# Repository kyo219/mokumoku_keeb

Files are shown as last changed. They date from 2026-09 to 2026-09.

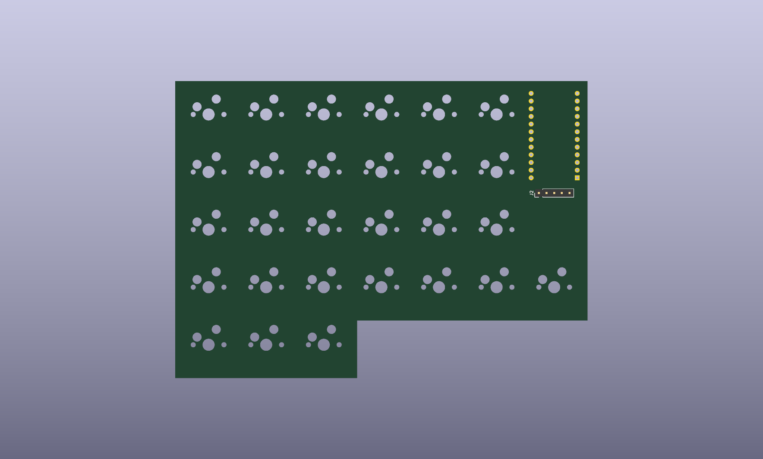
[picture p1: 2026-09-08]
assets/renders/pcb-left-top.png

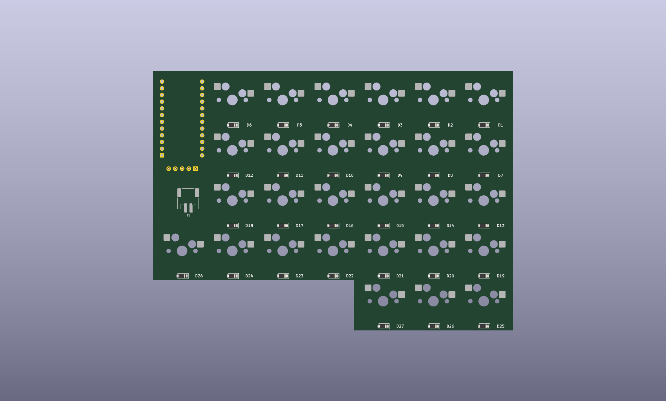
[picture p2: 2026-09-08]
assets/renders/pcb-left-bottom.png

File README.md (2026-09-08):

# mokumoku-keeb(仮称)

左右分割型・ワイヤレス・オーソリニアキーボードの設計リポジトリです。

> **注意**: `mokumoku-keeb` はリポジトリ名由来の仮slugです。正式な製品名は未定です。

## 現在の開発段階

**初期整備フェーズ(設計段階)** — 要件定義とドキュメント整備を行っている段階です。
KiCadの回路図・PCB、ケースCAD、製造データはまだ存在しません。**製造検証前であり、発注可能な状態ではありません。**

## 主な仕様

- 左右分割型オーソリニア配列(列スタッガー・キー回転なし)
- **片側28キー / 左右合計56キー**、全キー1u、キーピッチ19.05mm
- Cherry MX互換スイッチ(通常高さ、3ピン/5ピン対応)+ **Kailh MXホットスワップソケット**
- マイコン: **nice!nano v2**(または互換のPro Micro形状nRF52840)を左右に各1基、ソケット実装
- ディスプレイ: **nice!view**(左右各1、ソケット実装、nice!nanoの上に積層)
- ファームウェア: **ZMK**
- 接続: **Bluetooth LE**(ホスト接続・左右間ともに無線。TRRSケーブル不使用)
- 電源: 左右独立の3.7V LiPoバッテリー + 2ピンJSTコネクタ、USB-C充電
- **LED非搭載**(キーLED・RGB・アンダーグローなし)— 省電力・薄型化を優先
- MX互換を維持したまま可能な限り薄い、薄型サンドイッチ構造を基本案とする

## ドキュメント

| ドキュメント | 内容 |
| --- | --- |
| [docs/product-requirements.md](docs/product-requirements.md) | **仕様の一次情報**。確定要件・未確定事項の整理 |
| [docs/key-layout.md](docs/key-layout.md) | キー配列の定義(論理座標・ミラー規則) |
| [docs/architecture.md](docs/architecture.md) | システム構成図 |
| [docs/electrical.md](docs/electrical.md) | 電気設計(確定事項と検討中の候補) |
| [docs/mechanical.md](docs/mechanical.md) | 機構設計(プレート・ケース・積層) |
| [docs/firmware.md](docs/firmware.md) | ZMKファームウェア方針 |
| [docs/manufacturing.md](docs/manufacturing.md) | 製造方針(Rev.A) |
| [docs/bring-up.md](docs/bring-up.md) | 初号機のbring-up手順 |
| [docs/verification-checklist.md](docs/verification-checklist.md) | 3段階の検証チェックリスト |
| [docs/references.md](docs/references.md) | 参考資料・公式資料・ライセンス記録 |
| [docs/decisions/](docs/decisions/) | 設計判断のADR |
| [docs/revisions/rev-a.md](docs/revisions/rev-a.md) | Rev.Aの記録 |

## リポジトリ構成

```
.
├── AGENTS.md                 # AI・開発者向けの編集ルール
├── README.md
├── docs/                     # 仕様・設計ドキュメント(上表参照)
├── hardware/kicad/           # KiCadソース(回路図・PCB・プロジェクト固有ライブラリ)
├── mechanical/               # ケース・プレートのCADと出力物
├── firmware/zmk/             # ZMK設定・Shield定義
├── production/               # 発注用に凍結した製造データ(リビジョン別)
├── scripts/                  # 補助スクリプト
└── assets/renders/           # レンダリング画像等
```

このリポジトリを編集する際は、まず [AGENTS.md](AGENTS.md) を読んでください。

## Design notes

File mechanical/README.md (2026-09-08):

# mechanical/

ケース・プレートの機構設計を置くディレクトリ。設計方針は `docs/mechanical.md` を参照。
**CADデータはまだ作成していない**(初期整備フェーズ)。

| サブディレクトリ | 用途 |
| --- | --- |
| `cad/` | 編集可能なCADソース(FreeCAD / Fusion等。形式は未確定) |
| `plates/` | スイッチプレート(約1.5mm厚候補)の設計データ |
| `case/` | ケース(トップ・ボトム)の設計データ |
| `exports/` | STL / STEP / DXF などの出力物 |

- ソース(`cad/`)と出力物(`exports/`)を分離する。
- 発注に使う製造データは `production/<revision>/` へ凍結する(AGENTS.md参照)。

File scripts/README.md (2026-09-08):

# scripts/

補助スクリプト。標準ライブラリのみ使用(現状は追加依存なし。必要になったらuvで環境構築)。

| スクリプト | 役割 |
| --- | --- |
| `generate_left_schematic.py` | ADR-0002のマトリクス/GPIO定義から左基板回路図(`hardware/kicad/left/`)を生成。**回路図は生成物、こちらが編集対象**。ピン変更時はADR/electrical.mdと同時更新して再生成する |
| `verify_left_netlist.py` | 生成した回路図のネットリストをkicad-cliで書き出し、ADR-0002の期待結線(全COL/ROW/nice!view/電源ネット)と自動照合する |
| `generate_footprints.py` | カスタムフットプリント(`hardware/kicad/footprints/mokumoku_keeb.pretty/`)を公式データシート由来の座標で生成。検証状態は footprints/README.md の表を参照 |
| `generate_left_pcb.py` | 左基板PCBを生成(KiCad付属python3で実行)。ネットリスト読込→28キー配置→裏面ダイオード→nano/view/JST配置→切り欠き外形→アンテナkeep-out。配線は含まない |
| `render_concept_layout.py` / `render_side_view.py` | 概観モック(上面・断面)を `assets/renders/` に生成 |

前提: KiCad 10が `~/Applications/KiCad/` にあること。

```
python3 scripts/generate_left_schematic.py
python3 scripts/verify_left_netlist.py
~/Applications/KiCad/KiCad.app/Contents/MacOS/kicad-cli sch erc --severity-all \
  hardware/kicad/left/mokumoku_keeb_left.kicad_sch
```

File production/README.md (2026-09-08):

# production/

発注に使用した**製造データの凍結スナップショット**をリビジョン別に置くディレクトリ。**まだ製造データは存在しない**(発注可能な状態ではない)。

## 構成(予定)

```
production/
└── rev-a/
    ├── gerbers/     # Gerber・ドリル
    ├── bom/         # BOM
    ├── placement/   # 座標データ(CPL)
    └── README.md    # 発注日・発注先・仕様・元コミットの記録
```

## ルール

- ここへ置けるのは、`docs/verification-checklist.md` の製造前チェックリストを完了したデータのみ。
- 置いたデータは**凍結**し、以後編集しない。修正は次リビジョン(`rev-b/` 等)として作成する。
- 製造用の生成物をこのディレクトリ以外に置かない(AGENTS.md参照)。

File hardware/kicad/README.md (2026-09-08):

# hardware/kicad/

KiCadの**編集可能なソース**を置くディレクトリ。KiCad 10.0系を使用(`~/Applications/KiCad`)。

## 構成

- `left/` — **左基板プロジェクト(正)**。回路図はRev.Aドラフトあり(`scripts/generate_left_schematic.py` で生成、ERC 0違反・ネットリスト自動照合済み)。PCBは未着手
- `symbols/` — プロジェクト固有シンボル(`mokumoku_keeb.kicad_sym`: nice_nano_v2 = 公式ピン配置図と照合済み)
- `footprints/` — プロジェクト固有フットプリント(`.pretty`、まだなし)
- `3dmodels/` — 3Dモデル(まだなし)
- 右基板は左のミラーとして後続フェーズで生成(ADR-0001)

## 置かないもの

- Gerber・ドリル・BOM・座標データなどの**生成物** → `production/<revision>/` へ(AGENTS.md参照)

## ルール

- フットプリントは実部品データシートと照合し、検証状態を記録してから製造に使用する(未検証フットプリントの製造使用は禁止)。
- 外部ライブラリ由来のシンボル・フットプリントは出典とライセンスを `docs/references.md` に記録する。
- ERC/DRCを通してから製造候補とする。

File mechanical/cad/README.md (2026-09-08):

# cad/

編集可能なCADソースを置く(まだなし)。使用CADツール・ファイル形式は未確定。

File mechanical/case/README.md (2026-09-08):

# case/

ケースの設計データを置く(まだなし)。材質・固定方法は未確定(`docs/mechanical.md` 参照)。USB-C・リセット・電源スライドスイッチの開口とアンテナ周辺の非金属化が要件。

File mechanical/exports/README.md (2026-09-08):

# exports/

CADからの出力物(STL / STEP / DXF等)を置く(まだなし)。編集可能なソースは `cad/` へ。発注用データは `production/<revision>/` へ凍結する。

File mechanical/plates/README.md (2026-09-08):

# plates/

スイッチプレートの設計データを置く(まだなし)。約1.5mm厚を検討中。MX互換の開口寸法は公式資料照合後に確定する(`docs/mechanical.md` 参照)。

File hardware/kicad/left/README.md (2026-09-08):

# hardware/kicad/left/ — 左基板KiCadプロジェクト

左半分(正)のKiCadプロジェクト。**回路図・PCBともスクリプトによる生成物**であり、結線・配置の手編集は禁止(変更はADR・docs・スクリプトを同時更新して再生成)。

- `mokumoku_keeb_left.kicad_sch` — 回路図(`scripts/generate_left_schematic.py` の生成物、フットプリント割り当て済み)
- `mokumoku_keeb_left.kicad_pcb` — PCB(`scripts/generate_left_pcb.py` の生成物。**配置+外形+アンテナkeep-outまで。配線は未着手**)
- `mokumoku_keeb_left.kicad_pro` / `sym-lib-table` / `fp-lib-table` — プロジェクト設定とライブラリ参照

## 検証

```
python3 scripts/generate_left_schematic.py   # 回路図再生成
python3 scripts/verify_left_netlist.py       # ネットリストをADR-0002と自動照合
kicad-cli sch erc ...left.kicad_sch          # ERC(現在0違反)
<KiCad付属python3> scripts/generate_left_pcb.py   # PCB再生成
kicad-cli pcb drc ...left.kicad_pcb          # DRC(現在: 未配線92件のみ、他0違反)
```

## 状態・注意

- **Rev.Aドラフト。配線未着手であり製造可能ではない。**
- PCBの内容: 28キー(19.05mmグリッド、R0C0=(50,50))、裏面ダイオード、nice!nano(アンテナ=上端向き、ADR-0007)、nice!view用5ピンヘッダ、JST(裏面・C6タブ下部)、切り欠き外形、アンテナkeep-out rule area
- **SW29(スライドスイッチ)・SW30(リセット)は未配置**(検証済みフットプリントがないため。Alps図面入手・リセット部品選定後に配置)
- JST極性は「pin1=+」の**仮置き**(回路図上に注記あり)。実バッテリー確認後に確定(ADR-0003)。
- 右基板は本プロジェクトのミラーとして後続フェーズで生成する(ADR-0001)。

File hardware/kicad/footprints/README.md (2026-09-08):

# footprints/ — フットプリントと検証状態

**未検証のフットプリントを製造用に使用しない**(AGENTS.md)。使用するフットプリントは必ずこの表で状態を管理する。

カスタム品は `mokumoku_keeb.pretty/`(`scripts/generate_footprints.py` の生成物。手編集禁止、変更はスクリプト側で)。

| 部品 | フットプリント | 出所 | 検証状態 |
| --- | --- | --- | --- |
| MXスイッチ+Kailhホットスワップ | `mokumoku_keeb.pretty/SW_MX_HotSwap_Kailh_PG151101S11_1u` | 自作(Cherry MX公式+Kailh公式データシートから生成) | **図面照合済み**(穴位置=Cherry公式、Ø3.0ソケット穴=Kailh公式、pcbnewで座標を数値検証)。⚠️ SMDパッドの張り出し量(±3.175mm)は図面からの導出値 → **実物ソケットで発注前に要確認** |
| nice!nano v2(ソケット) | `mokumoku_keeb.pretty/nice_nano_v2` | 自作(2.54mmピッチ、行間15.24mm=Pro Micro慣例) | **暫定**。ピン番号=プロジェクトシンボルと一致(数値検証済み)。⚠️ ドリル1.0mmは**コンスルー公式図面で要確認**(ADR-0006)。外形・アンテナ領域は近似値 → 実物採寸で確定 |
| バッテリーコネクタ | `Connector_JST:JST_PH_S2B-PH-SM4-TB_1x02-1MP_P2.00mm_Horizontal`(KiCad標準) | KiCad公式ライブラリ(ePH.pdf準拠と明記) | **図面照合済み**(ピッチ2.0±0.05・補強パッド1.5×3.4が公式図面と一致)。⚠️ **極性(pin1=+の仮置き)は実バッテリーで要確認**(ADR-0003) |
| ダイオード 1N4148W | `Diode_SMD:D_SOD-123`(KiCad標準) | KiCad公式ライブラリ | **採用可**(SOD-123標準パッケージ。メーカー推奨パッドとの差異は手はんだ用途で許容) |
| nice!view 5ピン | `Connector_PinHeader_2.54mm:PinHeader_1x05_P2.54mm_Vertical`(KiCad標準) | KiCad公式ライブラリ | **採用可**(標準2.54mmピッチ)。ソケット高さ選定はADR-0006 |
| 電源スライドスイッチ SSSS811101 | **未作成** | — | **Alps公式PDF図面が未入手のため作らない**(推測で作成しない方針)。図面入手後に作成・照合 |
| リセットボタン | **未作成** | — | 型番未定のため未作成 |

## 検証ワークフロー

```
python3 scripts/generate_footprints.py     # カスタムFP再生成
# pcbnewで検証ボードに配置 → 座標数値チェック+PDF目視(scripts/内の手順参照)
```

発注前チェックリスト(docs/verification-checklist.md)で、上表の⚠️項目がすべて解消していることを確認すること。

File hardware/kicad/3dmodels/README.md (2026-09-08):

# 3dmodels/

KiCadで使用する部品の3Dモデルを置く(まだなし)。外部由来のモデルは出典・ライセンスを `docs/references.md` に記録すること。

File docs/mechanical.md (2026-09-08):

# 機構設計(Mechanical)

薄型化を重視するが、**通常高さのMX互換性と機械的強度を優先**する。

## 確定している機構要件

- 基本キーピッチ **19.05mm**、全キー1u、列スタッガー・回転なし
- 通常高さの**MX互換スイッチ**(3ピン/5ピン対応)+ Kailh MXホットスワップソケット
- **プレートなし構成にはしない**。**1.5mm厚のスイッチプレート**を用いた**薄型サンドイッチ構造**を基本案とする
  - Cherry公式データシート確認済み: **プレート開口14.0±0.05mm角(角R0.3max)、プレート厚1.5±0.1mm指定**([references.md](references.md))。1.5mm案は公式仕様どおり
  - 同データシートのPCB厚表記は約1.5mm(0.06±0.006in)→ **1.2mm板厚はCherryの想定外**であり、検証必須の追加根拠
- PCB厚は1.6mmを標準候補(1.2mmはソケット互換性・剛性確認後に判断)
- ホットスワップソケットと底板のクリアランスを最小化する
- キーLED等がないため、導光・透過に関する機構要件はない

## 基板・プレート外形の方針(確定)

- **PCB・プレート・ケースの外形は長方形にせず、キー領域に沿って切り欠く**([key-layout.md](key-layout.md) の外形方針に従う)。
- 具体的には、下段追加行(R4)は小指側3キー分のみ張り出し、その右側の下部領域(R4×C3–C6相当)は基板なし。親指側C6タブは1uキー+nice!view/nice!nano占有分のみ。
- ケース・プレートも同じ輪郭に追従させる(ケース余白・入隅Rは外形設計時に確定)。
- 注意点: 切り欠き形状のため、ねじ・スペーサー配置と剛性(特にC6タブと下段張り出しの根元)を外形設計時に確認する。

## 積層構造(基本案)

上から順に:

```
キーキャップ
MX互換スイッチ
スイッチプレート(約1.5mm)
(プレート〜PCB間の空間: MX規格による)
PCB(1.6mm標準候補)
ホットスワップソケット・ダイオード(PCB裏面)
(最小クリアランス)
底板
```

- **ホットスワップソケット(Kailh PG151101S11)のPCB裏面からの突出は1.85±0.1mm**(公式データシート確認済み)。PCB裏面〜底板の最小クリアランスはこの1.85mm+マージンが下限になる。
- Kailh公式の推奨レイアウトは**基板厚1.6mm前提**と明記されている。PCB1.2mm化はスイッチ保持力・ソケット嵌合の実物検証をしてから判断する(既存方針の根拠)。

- MXスイッチはプレート上面からPCB上面までの距離が規格で決まるため(データシートで確認)、薄型化の自由度は主に「PCB裏面〜底板」と「ケース縁の高さ」にある。
- スイッチのセンターポスト・固定ピンがPCBを貫通するため、底板との間に必要な逃げを確認する。

## nice!view / nice!nano の積層

- 追加1uキー(R3, C6)の真上の領域に **nice!view(公式確認済み: 14mm × 36mm、5ピン2.54mmピッチ)を縦向きに配置**し、その**下層にnice!nano(公式確認済み: 基板厚3.2mm、ミッドマウントUSB-C)を積層**する。
- 両方とも交換可能なソケット実装。ソケット+ピンヘッダの合計高さが確定するまで、この部分の最大高さは未確定。
- **nice!view装着中でも以下を操作可能にする**こと:
  - USB-C(ケース開口から抜き差し)
  - リセットボタン
  - 電源スライドスイッチ
- ソケットの具体部品(低背ソケット/コンスルー等)は未確定(ADR予定)。

## バッテリー配置

- 左右それぞれにLiPoを収納する。配置場所は未確定(候補: PCB下の空間のうちホットスワップソケット・アンテナ禁止領域と干渉しない領域)。
- **保護要件**:
  - ソケット・はんだ接合部の突起がバッテリーに接触しない構造にする
  - 底板との間で圧迫しない
  - **膨張余裕**(厚み方向のマージン)を確保する
- バッテリー寸法・容量は未確定。ケース内寸確定後に決める([product-requirements.md](product-requirements.md) 未確定事項)。

## ケース開口・操作部

| 操作部 | 要件 |
| --- | --- |
| USB-C | ケース装着後も抜き差し可能な開口 |
| リセットボタン | ケース外から操作可能(開口またはピンホール) |
| 電源スライドスイッチ | ノブをケース**側面**から操作可能。ON/OFF位置を目視・触覚で判別可能。ケースまたはPCBにON/OFF表示。ノブの突出量を抑えて誤操作を防ぐ。**配置方針(2026-09-08、暫定): C6タブの外周側面、nice!view下部〜親指キー横**(アンテナkeep-outから離れ、nice!view/nano・JSTと近く配線が短い)。右半分はミラー |

## アンテナ周辺

- nice!nanoのアンテナ端周辺は**非金属化**する: 金属プレート・ねじ・バッテリー・金具を配置しない。
- プレートを金属にする場合でも、アンテナ上方は切り欠くか非金属材にする(材質未確定のため後続フェーズで具体化)。

## ケース製作方針(2026-09-08確定、ADR-0008)

- **フル樹脂の削り出しを基本方針**とする(POM/PC候補、具体材質未定)。フルアルミはアンテナ遮蔽のため不採用。
- 進め方: PCBレイアウト確定 → **3Dプリント試作**(干渉・開口・BLE実測検証)→ 樹脂削り出し発注。
- CADはCadQuery等でのスクリプト生成を基本とし、PCB外形に追従させる。発注データは `production/<revision>/` に凍結。

## 未確定事項

- ケースの具体材質(POM / PC等)・色と固定方法(ねじ/スペーサー構成)
- プレート材質(FR4 / ポリカーボネート / アルミ(アンテナ部除く)等)
- 正確な外形寸法・ケース余白(nice!view 14×36mmは確認済み。ソケット高さと余白が未確定)
- nice!view/nice!nanoソケットの型番と積層高さ
- バッテリー寸法・配置
- 底板とソケット間の具体的クリアランス値

これらは実部品の公式寸法資料([references.md](references.md))を確認後、ADRで確定する。

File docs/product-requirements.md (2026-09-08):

# 製品要件定義(Product Requirements)

**このドキュメントが仕様の一次情報です。** 他のドキュメントと矛盾した場合はこちらが正です。

- プロジェクト名: **mokumoku-keeb(仮称)** — リポジトリ名由来の仮slug。正式名は未定。
- ステータス: 初期整備フェーズ(設計段階、製造検証前)

## 1. 確定要件

### 製品コンセプト

- 左右分割型・Bluetooth対応・バッテリー駆動のオーソリニアキーボード
- 通常高さのMX互換スイッチを使用しつつ、LEDを省略し、省電力かつ可能な限り薄い構造を目指す
- 薄型化より、MX互換性と機械的強度を優先する

### キー配列(詳細は [key-layout.md](key-layout.md))

- 左半分を基準に設計し、右半分は完全な左右反転形状
- 基本4行×6列のオーソリニア24キー + 小指側3列の第5行3キー + 親指側1uキー1個 = **片側28キー、左右合計56キー**
- 全キー1u、基本キーピッチ19.05mm
- 列スタッガー・キー回転は使用しない
- 追加の1uキーはSpace専用ではなく汎用キーとして扱う
- **基板・プレート・ケースの外形は長方形にせず、キー領域(+nice!view/nice!nano領域)に沿って切り欠く**。キーが入らない領域(R4×C3–C6相当の下部など)には基板を設けない(2026-09-08確定。詳細は [key-layout.md](key-layout.md))

### スイッチ

- 通常高さのCherry MX互換スイッチ(3ピンおよび5ピン対応)
- Kailh MXホットスワップソケット
- Kailh Choc等のロープロファイル規格には**対応しない**
- 全キーにマトリクス用ダイオードを設ける
- キーLED・RGB LED・アンダーグローは**搭載しない**

### マイコン・無線

- 左右それぞれに独立したnRF52840マイコン
- nice!nano v2、または互換性が明確なPro Micro形状のnRF52840マイコン
- Raspberry Pi Pico / RP2040 は**使用しない**
- マイコンは交換可能な低背ソケット実装
- ファームウェアはZMK
- ホスト接続・左右間接続ともにBluetooth LE(TRRS等の有線接続は使用しない)
- ケース装着後もUSB-Cを利用可能にする
- Bluetoothアンテナの禁止領域(keep-out)を確保する

### nice!view

- ディスプレイはnice!view専用(OLED互換性は不要)
- 標準的な5ピン接続とSPI配線に対応
- 左半分では親指側追加1uキー(R3, C6)の真上へ縦向きに配置、右半分は左右反転
- nice!viewの下に重なるようにnice!nanoを配置
- nice!view・nice!nanoともに交換可能なソケット実装
- 電源スイッチ・リセット・USB-Cはnice!view装着中も操作可能にする
- nice!viewはキー数に含めない

### バッテリー・電源

- 左右それぞれ独立した3.7V LiPoバッテリーで駆動
- 左右それぞれに2ピンJSTバッテリーコネクタを搭載
- nice!nanoのUSB-C経由で充電
- 左右それぞれにリセットボタンを設置
- 電源はON/OFF位置が明確な2ポジション式スライドスイッチ
  - スライドノブはケース側面から操作可能
  - ON/OFF状態を目視および触覚で判別可能にする
  - PCBまたはケースにON/OFF表示を設ける
  - 持ち運び中の誤操作を防ぐため、ノブの突出量を抑える
- LiPoをソケット・はんだ接合部・底板から保護し、膨張余裕を確保する

### 開発プロセス

- 初号機(Rev.A)はPCBのみを発注し、手実装する
- Rev.Aを評価し、必要に応じてRev.Bで修正する
- 未確認の寸法・ピン配置・極性・フットプリントを推測で確定しない
- 「製造可能」「検証済み」「production-ready」等の表現は条件を満たすまで使用しない

## 2. 推奨要件(基本案。検証結果により変更可)

- プレートなし構成にはせず、**薄型サンドイッチ構造**を基本案とする
- スイッチプレートは約**1.5mm厚**を検討する
- PCB厚は**1.6mmを標準候補**とし、1.2mmは互換性(ホットスワップソケット・スイッチ保持力)と剛性を確認してから判断する
- ホットスワップソケットと底板のクリアランスを最小化する
- アンテナ周辺へ銅箔・金属プレート・バッテリー・ねじを配置しない

## 3. 未確定事項

| # | 項目 | 決定方法 | 記録先 |
| --- | --- | --- | --- |
| 1 | 正式な製品名 | ユーザーが決定 | 本ドキュメント |
| 2 | ~~左右別PCB か リバーシブルPCB か~~ | **確定: 左右別PCB**([decisions/0001](decisions/0001-separate-left-right-pcbs.md)) | 確定済み |
| 3 | PCB厚(1.6mm標準候補 / 1.2mm) | ソケット互換性・剛性の確認後 | [decisions/](decisions/) |
| 4 | ~~マトリクス構成~~ | **確定: 物理一致の5行×7列**([decisions/0002](decisions/0002-matrix-and-gpio.md)) | 確定済み |
| 5 | ~~GPIO割り当て~~ | **確定**([decisions/0002](decisions/0002-matrix-and-gpio.md)。PCB配線でRow/Col個別入れ替えの可能性のみ残る) | 確定済み |
| 6 | バッテリーの寸法と容量 | **500mAh以下方針は確定**([decisions/0004](decisions/0004-power-slide-switch-alps.md))。具体型番はケース内寸確定後 | ADR |
| 7 | JSTコネクタ | **型番確定: JST PH / S2B-PH-SM4-TB**([decisions/0003](decisions/0003-battery-connector-jst-ph.md))。**極性のみ実バッテリー確認後** | 極性のみ未確定 |
| 8 | ~~スライドスイッチの型番~~ | **確定: Alps SSSS811101**([decisions/0004](decisions/0004-power-slide-switch-alps.md)。BOOST充電は使用禁止) | 確定済み |
| 9 | プレート・ケースの材質と固定方法 | **ケースはフル樹脂削り出し方針で確定**([decisions/0008](decisions/0008-case-material-resin.md)、POM/PC候補)。具体材質・固定方法・プレート材質は未確定 | [mechanical.md](mechanical.md) / ADR |
| 10 | nice!view / nice!nano ソケット | **方式確定: コンスルー第一候補**([decisions/0006](decisions/0006-mcu-display-sockets.md))。型番・高さは図面確認後 | 型番のみ未確定 |
| 11 | ~~ダイオードの型番・実装形態~~ | **確定: 1N4148W(SOD-123)**([decisions/0005](decisions/0005-matrix-diode-1n4148w.md)) | 確定済み |
| 12 | 正確な外形寸法(ケース余白に依存。nice!view寸法は14×36mmで確認済み) | 後続フェーズ | [mechanical.md](mechanical.md) |

## 4. 対象外(スコープ外)

- キーLED・RGB LED・アンダーグロー
- Kailh Choc等のロープロファイルスイッチ対応
- OLEDディスプレイ互換
- TRRS等の有線での左右接続
- Raspberry Pi Pico / RP2040系マイコン
- 列スタッガー・キー回転を伴う配列
- (初期フェーズでは)KiCad回路図・PCB・Gerber・製造データ・ケースCADの完成、製造発注、外部サービスへのアップロード

## 5. 初号機(Rev.A)の成功条件

Rev.A(PCBのみ発注・手実装)が以下をすべて満たすこと:

1. 短絡・逆極性なくUSB-Cから給電・充電できる
2. nice!nanoがソケット実装で認識され、ZMKを書き込める
3. 全56キーがマトリクスとして正しく入力される(ゴースト・チャタリングの構造的問題がない)
4. nice!viewがソケット実装で表示動作する
5. 左右間がBLEで接続され、ホストともBLE接続できる
6. 左右それぞれがバッテリー単独で駆動する
7. アンテナ禁止領域が確保され、実用的なBLE接続性が得られる
8. ケース装着を想定した部品高さ・開口位置に致命的な干渉がない(ケース自体はRev.A時点で完成していなくてよい)

満たせなかった項目はRev.Bの修正対象として [revisions/rev-a.md](revisions/rev-a.md) に記録する。

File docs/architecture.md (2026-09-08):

# システム構成(Architecture)

左右分割・完全無線のシステム構成を示す。左右は対称構成(右は物理左右反転)。

## 構成要素

各半分(左・右)がそれぞれ以下を持つ:

- **nice!nano v2**(nRF52840、ソケット実装、USB-C付き)
- **キーマトリクス**(28キー + 全キーにダイオード、ホットスワップソケット)
- **nice!view**(SPI接続、5ピン、ソケット実装、nice!nanoの上に積層)
- **3.7V LiPoバッテリー**(2ピンJSTコネクタ経由、電源スライドスイッチ、リセットボタン)

左右間およびホストとの接続はすべてBluetooth LE。有線の左右接続は存在しない。

## ブロック図

```mermaid
graph TB
    subgraph Left["左半分"]
        LB["LiPo 3.7V"] -->|JST 2pin / スライドSW| LN["nice!nano v2 (nRF52840)"]
        LM["キーマトリクス 28キー<br/>(ダイオード + ホットスワップ)"] -->|GPIO row/col| LN
        LN -->|SPI 5pin| LV["nice!view"]
        LUSB["USB-C"] -->|給電・充電・書き込み| LN
        LN -->|充電| LB
    end

    subgraph Right["右半分"]
        RB["LiPo 3.7V"] -->|JST 2pin / スライドSW| RN["nice!nano v2 (nRF52840)"]
        RM["キーマトリクス 28キー<br/>(ダイオード + ホットスワップ)"] -->|GPIO row/col| RN
        RN -->|SPI 5pin| RV["nice!view"]
        RUSB["USB-C"] -->|給電・充電・書き込み| RN
        RN -->|充電| RB
    end

    Host["ホスト (PC / タブレット等)"]
    LN <-->|BLE split接続| RN
    LN <-->|BLE HID| Host
```

## 役割の考え方

- ZMKのsplit構成では、片側が **central**(ホストとBLE接続し、もう片側の入力を統合)、
  もう片側が **peripheral**(centralへBLEで入力を送る)となる。
- どちらをcentralにするかは未確定(ZMKのデフォルトと消費電力特性を確認して決定。[firmware.md](firmware.md) 参照)。
- ハードウェアは左右対称に設計し、central/peripheralの区別はファームウェア側でのみ行う。

## 電源経路

```
USB-C ─→ nice!nano(充電回路内蔵)─→ LiPo充電
LiPo ─→ JST 2pin ─→ 電源スライドスイッチ ─→ nice!nano(電源入力)
```

- 充電はnice!nano内蔵の充電回路に任せる(外付け充電ICは設けない)。
- スライドスイッチの挿入位置(バッテリー正極ラインを切るのか、nice!nanoの想定するスイッチ端子を使うのか)は
  nice!nanoの公式ピン配置を確認してから確定する([electrical.md](electrical.md) の未確定事項)。

## 責務の分離

| 領域 | ドキュメント | 内容 |
| --- | --- | --- |
| 電気 | [electrical.md](electrical.md) | マトリクス、GPIO、ダイオード、電源、nice!view配線 |
| 機構 | [mechanical.md](mechanical.md) | 積層構造、プレート、ケース、バッテリー配置 |
| ファームウェア | [firmware.md](firmware.md) | ZMK split設定、Shield定義、キーマップ |

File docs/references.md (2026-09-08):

# 参考資料・出典記録(References)

**公式資料を優先する。** 確認できていない内容を「確認済み」と記載しないこと。
外部設計を参考にした場合は、参考箇所・出典・ライセンスをこのファイルに追記する。

## 確認済み資料

### nice!nano v2(確認日: 2026-09-08)

出典: [nicekeyboards.com — nice!nano Docs](https://nicekeyboards.com/docs/nice-nano/) / [Pinout and Schematic](https://nicekeyboards.com/docs/nice-nano/pinout-schematic)(公式ピン配置図 pinout-v2.png・回路図画像を目視確認)

- MCU: nRF52840(Flash 1MB / RAM 256KB)
- USB-Cはミッドマウントで基板全体厚 **3.2mm**
- 使用可能GPIO: ヘッダー18ピン + 裏面パッド3ピン(P1.01 / P1.02 / P1.07)= **計21ピン**(裏面にSWC/SWDパッドもあり)
- ピン配置(公式図より。D番号=Pro Micro互換名):
  - 左列(上→下): GND, **D1=P0.06**, **D0=P0.08**, GND, GND, **D2=P0.17**, **D3=P0.20**, **D4=P0.22**, **D5=P0.24**, **D6=P1.00**, **D7=P0.11**, **D8=P1.04**, **D9=P1.06**
  - 右列(上→下): **BATTERY+**, **BATTERY+**, GND, **RESET**, **3.3V(VCC)**, **D21=P0.31**, **D20=P0.29**, **D19=P0.02**, **D18=P1.15**, **D15=P1.13**, **D14=P1.11**, **D16=P0.10**, **D10=P0.09**
- 電源・充電:
  - 3.7V LiPo前提。充電電流は標準 **約100mA**、基板上の「BOOST」ジャンパをブリッジすると **約500mA**(**500mAh超のバッテリーのみ**。公式が小容量への使用を明確に警告)
  - **P0.13をLowにすると3.3V VCCピンの出力を遮断**できる(オンボードMOSFET、外部部品の待機電力削減用)
  - 回路図はブロックとして「Charging and Power Path」「VCC Regulator and Cut Off」「USB Port」「Status LED」を確認(個別部品定数までは画像解像度の都合で未確認)
- バッテリー残量: ZMK公式ボード定義で `zmk,battery-nrf-vddh`(VDDH電圧測定)を使用 → **ADC用GPIOを消費しない**(v1のP0.04測定とは異なる)
- ⚠️ 未確認のまま: アンテナkeep-outの公式推奨寸法(公式ドキュメントに記載を発見できず)、公式の電源スイッチ推奨接続位置

### nice!view(確認日: 2026-09-08)

出典: [nicekeyboards.com — nice!view Docs](https://nicekeyboards.com/docs/nice-view/) / Pinout and Schematic(公式ピン配置図・寸法図を目視確認)

- 外形: **14mm × 36mm**(V-Cutにより+0.1〜0.2mmの可能性、公式図注記)、基板厚約1mm+ディスプレイ約1mm
- ピン: **5ピン、左から MOSI, SCK, VCC, GND, CS**、ピッチ **2.54mm**、端から1.92mm
- ディスプレイ: Sharpメモリ液晶(LS0xx系)**160×68**、SPI(ZMK定義で最大1MHz)、**CSはactive-high**、MISO不要
- OLED互換ソケットで使う場合はCSをD1へ配線する慣例(本プロジェクトはネイティブ5ピン接続なので該当せず)

### ZMK公式リポジトリ(確認日: 2026-09-08)

出典: [github.com/zmkfirmware/zmk](https://github.com/zmkfirmware/zmk)(mainブランチ、**MITライセンス**)

- `app/boards/nicekeyboards/nice_nano/nice_nano_nrf52840_zmk_2_0_0.overlay`:
  - `EXT_POWER` ノード = **P0.13 / GPIO_ACTIVE_HIGH**(VCC遮断制御)
  - バッテリー = `zmk,battery-nrf-vddh`
- `app/boards/shields/nice_view/nice_view.overlay`: `sharp,ls0xx` 160×68、SPI max 1MHz
- `app/boards/shields/nice_view_adapter/boards/nice_nano_nrf52840_zmk.overlay`(**標準ピン割り当て**):
  - SCK = P0.20(D3)、MOSI = P0.17(D2)、CS = pro_micro 1(D1=P0.06、active-high)、MISO = P0.25(ダミー、ヘッダー外)
- Helix / Corne 等のshield定義が同リポジトリに存在し、split構成の実装例として参照可能

### Kailh MXホットスワップソケット PG151101S11(確認日: 2026-09-08)

出典: Kailh(Kaihua Electronics)Product Specification KH-PS1607-10 Rev.B([keyboardio/keyswitch_documentationミラー](https://github.com/keyboardio/keyswitch_documentation/blob/master/datasheets/Kailh/PG151101S11-MX-Socket.pdf)。通称CPG151101S11)

- 本体高さ(PCB裏面からの突出): **1.85±0.1mm**、本体外形 10.90×5.89mm、厚み方向断面 3.05mm(端子部含む)
- スイッチピン受け穴: Ø3.00mm×2(水平間隔6.35mm、垂直オフセット2.54mm)— MXピン位置と一致
- **推奨PCBレイアウトは基板厚1.6mm(単面)前提**と明記 → 1.2mm化の検証課題の根拠
- 定格: 12V/10mA max(信号用)、挿抜寿命100サイクル、手はんだ350℃/3秒以内

### Alps Alpine スライドスイッチ SSSS811101(確認日: 2026-09-08)

出典: [Alps Alpine公式製品ページ](https://tech.alpsalpine.com/e/products/detail/SSSS811101/)

- 単極・2ポジション、表面実装(リフロー)、本体 6.7×2.6×1.4mm、アクチュエータ高1.1mm、トラベル1.5mm
- **定格 0.3A 5V DC max** / 50μA 3V DC min、動作温度 -40〜+85℃
- ⚠️ 流通サイトの寸法表記(7.7×5×1.9mm等)と公式値に差異あり(端子込み外形の可能性)。**公式PDF図面での照合をフットプリント作成時に必須とする**

### JST PHコネクタ(確認日: 2026-09-08)

出典: [JST公式データシート ePH.pdf](https://www.jst-mfg.com/product/pdf/eng/ePH.pdf)、[DigiKey製品ページ](https://www.digikey.com/en/products/detail/jst-sales-america-inc/S2B-PH-SM4-TB/926655)

- PHシリーズ: 2.0mmピッチ、定格2A/100V AC・DC、-25〜+85℃
- S2B-PH-SM4-TB(LF)(SN): 2ピン・表面実装・横型(サイドエントリー)
- ⚠️ **極性は規格で定まらない**。購入バッテリーの実物極性確認が必須(ADR-0003)

### Cherry MXスイッチ 公式データシート(確認日: 2026-09-08)

出典: Cherry MX Series(MX1A)Keyswitchデータシート([Octopartミラー](https://datasheet.octopart.com/MX1A-11NW-Cherry-datasheet-34676.pdf))

- **プレート(Metal Frame)開口: 14.0±0.05mm角(0.551±0.002in)、角R0.3max、プレート厚1.5±0.1mm(0.06±0.004in)指定** → 1.5mmプレート方針の公式裏付け
- PCBレイアウト(グリッド1.27mm): センターポスト穴 Ø4.0(0.157±0.004in)中央、固定ピン穴 Ø1.7(0.067±0.002in)を(±5.08, 0)、端子穴 Ø1.5(0.059±0.002in)
- PCBマウント図のPCB厚表記は 0.06±0.006in(≈1.5mm)→ **1.2mm板厚はCherryの想定外**(ソケット保持力検証の追加根拠)
- 本体 15.6mm角、キャップなし高さ11.6mm、トラベル4mm、定格 12V/10mA
- KiCad標準 `Button_Switch_Keyboard:SW_Cherry_MX_1.00u_PCB` の座標(端子(2.54,-5.08)/(-3.81,-2.54)、固定ピン±5.08)と一致することを確認

### JST PH SMTサイドエントリー推奨パターン(確認日: 2026-09-08)

出典: 上記ePH.pdf p.2(SMT type / Side entry type)

- 信号パッドピッチ 2.0±0.05mm、補強(MP)パッド 1.5±0.1 × 3.4±0.1mm
- KiCad標準 `Connector_JST:JST_PH_S2B-PH-SM4-TB_1x02-1MP_P2.00mm_Horizontal` と照合し一致(同フットプリントはePH.pdfを出典として明記)

### 1N4148W ダイオード(確認日: 2026-09-08)

出典: [Diodes Inc. 製品ページ](https://www.diodes.com/part/view/1N4148W)、[MCC データシート](https://www.mccsemi.com/pdf/Products/1N4148W(SOD-123).pdf)ほか複数メーカー

- 小信号高速スイッチングダイオード、SOD-123、VR 75V / VRRM 100V、IF 150mA、trr約4ns
- 複数メーカーが製造するセカンドソース定番品

## 今後確認すべき資料(未確認)

| # | 資料 | 確認したい内容 | 状態 |
| --- | --- | --- | --- |
| 1 | nice!nanoアンテナkeep-out実例 | 実績あるnice!nanoボード(FelixKeeb等)のkeep-out寸法実例(暫定方針はADR-0007) | 未確認 |
| 2 | ZMK公式ドキュメント(zmk.dev) | split詳細設定、peripheral電池残量のcentral集約表示のサポート状況、省電力設定 | 未確認 |
| 3 | Cherry MX(または互換)公式寸法資料 | プレート開口、プレート〜PCB距離、ピン位置(3/5ピン)、センターポスト径 | 未確認 |
| 4 | Alps SSSS811101 公式PDF図面 | フットプリント寸法・ノブ形状(公式ページ数値は確認済み。流通表記との差異解消) | 未確認 |
| 5 | コンスルー(Mac8)公式図面 | 型番、高さ(2.5/3.5mm)、対応基板厚、推奨穴径(ADR-0006の確定条件) | 未確認 |
| 6 | Mill-Max 315系ソケット図面 | 代替ソケットの高さ・穴径(コンスルー不適合時の代替) | 未確認 |
| 7 | LiPoバッテリー仕様(型番未定) | 寸法、容量(≤500mAh方針、ADR-0004)、保護回路、コネクタ極性 | 未確認 |
| 8 | nice!view用5ピン低背ソケットの図面 | 高さ(積層クリアランス計算後に選定) | 未確認 |
| 9 | P0.09/P0.10(D10/D16)のNFCピン扱い | nice!nanoボード定義でGPIO化済みかの確認(nfct-pins-as-gpios) | 未確認 |

## 参考にする公開設計(参考のみ。無断複製禁止)

| 設計 | 参考にしたい点 | ライセンス | 参照状況 |
| --- | --- | --- | --- |
| FelixKeeb | 薄型MX+無線構成の考え方 | 未確認 | 未参照(今後確認) |
| Helix | 左右分割・リバーシブルPCBの構成 | 未確認 | ZMK shield定義のみ参照(MIT) |
| Corne (crkbd) | split+nice!nano/nice!view運用、ZMK shield構成 | 未確認 | ZMK shield定義のみ参照(MIT) |

**運用ルール:**

- 実際に参照した時点で、参照したリビジョン/URL・参考にした具体的箇所・ライセンス条項をこの表に記録する。
- 回路・フットプリント・基板データをそのまま流用する場合は、ライセンスが許諾しているかを確認し、必要な帰属表示を行う。
- 「参考にした」と「流用した」を区別して記録する。

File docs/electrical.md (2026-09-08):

# 電気設計(Electrical)

現時点で確定している電気要件と、未確定事項の候補・検証方法を記録する。
**マトリクス構成(5行×7列)とGPIO割り当ては確定済み**([decisions/0002](decisions/0002-matrix-and-gpio.md)、2026-09-08承認)。PCB配線の都合によるRow/Col個別ピンの入れ替えのみあり得る(その場合は回路図・本GPIO表・ZMK設定を同時更新)。

## 確定している電気要件

- マイコン: nice!nano v2(または互換のPro Micro形状nRF52840)、低背ソケット実装
- 全28キー(片側)にマトリクス用ダイオードを1個ずつ設ける
- スイッチはKailh MXホットスワップソケット経由で接続
- nice!viewを5ピン(MOSI / SCK / VCC / GND / CS、2.54mmピッチ)で接続、ソケット実装
- 左右それぞれに: 3.7V LiPo + 2ピンJSTコネクタ、2ポジション式電源スライドスイッチ、リセットボタン
- 充電はnice!nanoのUSB-C経由(内蔵充電回路: 標準約100mA、BOOSTジャンパで約500mA ※500mAh超バッテリー限定)
- バッテリー残量測定はnice!nano v2のVDDH測定(`zmk,battery-nrf-vddh`)→ **ADC用GPIO不要**
- キーLED・RGB・アンダーグローの回路は設けない
- Bluetoothアンテナ禁止領域を基板上に確保する(銅箔・ベタGND含め非配置)

## nice!nano v2 ピン一覧(公式ピン配置図で確認済み。[references.md](references.md))

| Pro Micro名 | nRFポート | 位置 | 本設計での用途(確定) |
| --- | --- | --- | --- |
| D1 | P0.06 | 左列 | nice!view **CS**(ZMK標準) |
| D0 | P0.08 | 左列 | 予備(テストパッド候補) |
| D2 | P0.17 | 左列 | nice!view **MOSI**(ZMK標準) |
| D3 | P0.20 | 左列 | nice!view **SCK**(ZMK標準) |
| D4 | P0.22 | 左列 | マトリクス Row0 |
| D5 | P0.24 | 左列 | マトリクス Row1 |
| D6 | P1.00 | 左列 | マトリクス Row2 |
| D7 | P0.11 | 左列 | マトリクス Row3 |
| D8 | P1.04 | 左列 | マトリクス Row4 |
| D9 | P1.06 | 左列 | マトリクス Col0 |
| D10 | P0.09 | 右列 | マトリクス Col1※NFCピン注意 |
| D16 | P0.10 | 右列 | マトリクス Col2※NFCピン注意 |
| D14 | P1.11 | 右列 | マトリクス Col3 |
| D15 | P1.13 | 右列 | マトリクス Col4 |
| D18 | P1.15 | 右列 | マトリクス Col5 |
| D19 | P0.02 | 右列 | マトリクス Col6 |
| D20 | P0.29 | 右列 | 予備(テストパッド候補) |
| D21 | P0.31 | 右列 | 予備(テストパッド候補) |
| — | P1.01/P1.02/P1.07 | 裏面パッド | 使用しない(ソケット実装と両立しにくい) |
| — | P0.13 | 内部 | VCC遮断MOSFET制御(ZMKの `EXT_POWER`) |
| BATTERY+ ×2 / GND / RESET / VCC | — | 右列上部 | 電源・リセット |

- ※ P0.09/P0.10はnRF52840のNFC兼用ピン。nice!nanoボード定義でGPIO化されている前提だが、**設定(nfct-pins-as-gpios相当)の確認を検証項目とする**([references.md](references.md) #10)。
- 電力面の補足: nRF52840のP0.13等「低周波(standard-drive)推奨ポート」と高周波ポートの使い分けはBLE動作中のノイズ対策として言及されることがあるが、キーマトリクス用途では実害が小さい想定。問題があればRev.Aで実測評価する。

## マトリクス方式(確定: 5行×7列)

| 候補 | 構成 | 必要GPIO | 評価 |
| --- | --- | --- | --- |
| **A. 物理一致 5行×7列**(採用) | 35座標中28使用 | 12 | 配線が物理配置と一致し最も素直。デバッグ容易。GPIOは18ピン中15ピン(nice!view除く)で収まり、予備3ピン残る |
| B. 詰め替え 4行×7列 | 28座標ぴったり | 11 | GPIO1本節約できるが、R4の3キーとR3C6を電気的に別の行へ折り込むため配線が交差し、手実装・デバッグ時の混乱リスクが増える |

- **決定: 候補A(5行×7列)**(ADR-0002)。diode directionはcol2rowを第一候補とする。GPIOに余裕があり節約の必要がないため、追跡しやすさを優先。
- ZMKのkscanは `col2row`(COLから出力、ROWで読む方向はZMK設定に従う)を第一候補とし、ダイオードはスイッチ→ROW方向(カソード=ROW側)で統一する。最終的な向きはkscan設定確定時に回路図と同時にレビューする。
- 右半分も同一のマトリクス構成(左右対称)。ZMKのmatrix transformで56キーへ合成する。

## nice!view配線(確定: ZMK標準)

ZMK公式 `nice_view_adapter` の標準割り当てに合わせる(独自ピンにするとshield定義の流用性が下がるため):

| nice!view側ピン | 接続先 | 備考 |
| --- | --- | --- |
| MOSI | D2 = P0.17 | SPIM_MOSI |
| SCK | D3 = P0.20 | SPIM_SCK |
| VCC | nice!nano VCC(3.3V) | P0.13のMOSFETで遮断可能な系統。スリープ時に表示電源を切れる |
| GND | GND | |
| CS | D1 = P0.06 | **active-high**(ZMK定義) |

- MISOは不要(Sharpメモリ液晶は書き込み専用)。SPIMのMISO割り当てはヘッダー外のP0.25ダミーでよい(ZMK標準と同じ)。
- nice!view(14×36mm)はR3C6キーの真上に縦向き配置([key-layout.md](key-layout.md))。基板上は5ピンソケットを配置する。

## 電源スイッチ配線(候補)

- 候補A(第一候補): **BATTERY+ ラインにスライドスイッチを直列挿入**(JST+ → スイッチ → nice!nano BATTERY+)。OFFで完全遮断。
- 検証事項: OFF状態でUSB-Cを挿した場合の挙動(充電回路はBATTERY+側にあるため、**OFF中は充電されない**はず。仕様として許容するか確認)、スイッチの定格電流(充電時最大500mA以上を推奨)。
- 公式の推奨接続位置は文書で確認できていないため、回路図作成時にnice!nano回路図(Charging and Power Pathブロック)と突き合わせる。

## リセット回路

- RESETピンをGNDへ落とすタクトスイッチ(ダブルタップでUF2ブートローダ)。型番・ケース開口方法は未確定。

## テストパッド(候補)

- VBAT(スイッチ後)、VCC(3.3V)、GND、RST、予備GPIO(D0 / D20 / D21)、必要に応じて各Row/Col。基板設計時に確定。

## アンテナ禁止領域

- **公式のkeep-out推奨寸法は確認できていない**(公式docsに記載なし)。
- 方針: nice!nanoのアンテナ端(USB-Cと反対側)の下および周辺に全層銅箔禁止・部品/ねじ/バッテリー禁止の領域を設ける。具体寸法は参考設計とnRF52840モジュール一般則を調査してADRで確定する。

## 部品選定(2026-09-08 提案。ADR-0003〜0007参照)

| 部品 | 選定 | ADR |
| --- | --- | --- |
| バッテリーコネクタ | JST PH 2.0mm / S2B-PH-SM4-TB(LF)(SN)(SMD横型)。**極性は実バッテリー確認後に確定** | [0003](decisions/0003-battery-connector-jst-ph.md) |
| 電源スライドスイッチ | Alps Alpine SSSS811101(定格0.3A → **BOOSTジャンパ使用禁止**、充電は約100mAのみ) | [0004](decisions/0004-power-slide-switch-alps.md) |
| マトリクスダイオード | 1N4148W(SOD-123、セカンドソース可) | [0005](decisions/0005-matrix-diode-1n4148w.md) |
| nice!nano/nice!viewソケット | コンスルー第一候補 + 5ピン低背ソケット(型番・高さは図面確認後) | [0006](decisions/0006-mcu-display-sockets.md) |
| アンテナkeep-out | アンテナ端を基板端へ+投影領域+5mm全層keep-out(暫定) | [0007](decisions/0007-antenna-keepout-policy.md) |

## 未確定事項まとめ

| 項目 | 状態 |
| --- | --- |
| JST極性 | 未確定(購入バッテリーの実物極性確認後に回路図で確定) |
| バッテリー容量・寸法 | 未確定(**500mAh以下方針**=ADR-0004の帰結。ケース内寸確定後に選定) |
| コンスルー型番・高さ / nice!viewソケット高さ | 未確定(公式図面確認後、ADR-0006を更新) |
| アンテナkeep-outの最終寸法 | 暫定5mm(ADR-0007)。Rev.A実測で検証 |

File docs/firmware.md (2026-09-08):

# ファームウェア方針(ZMK)

ファームウェアは**ZMK**を使用する。
**この段階では、動作未確認の完成版ZMK設定を作らない。** GPIO割り当て確定後に実装する。

## split構成

- 左右それぞれのnice!nano v2にZMKを書き込む。
- ZMKのsplit機能で、片側が**central**(ホストとBLE HID接続し、peripheral側の入力を統合)、
  もう片側が**peripheral**(キー入力をcentralへBLE送信)となる。
- ZMKの慣例では左がcentralだが、どちらにするかは未確定(バッテリー消費が非対称になる点を考慮して決定)。
- ハードウェアは左右対称とし、central/peripheralはビルド設定でのみ区別する。

## 論理配置

- 全56キー(片側28キー)。物理配置は [key-layout.md](key-layout.md) を一次情報とする。
- **物理配置と論理マトリクスを分離する**:
  - kscanのrow/col構成は電気設計([electrical.md](electrical.md))で決まる(物理の5行×7列と一致しなくてよい)
  - matrix transform で kscan座標 → キーマップ位置へ変換する
  - 右半分はtransformのcol-offset(またはミラー定義)で吸収する

## nice!view対応

- ZMKのnice!view shield機構を利用する(`nice_view`アダプタ相当の構成)。
- SPIピン割り当てはZMK既定と実配線の整合を確認する(GPIO確定後)。

## バッテリー残量表示

- nice!nanoのバッテリー電圧監視(ADC)を有効化し、nice!view上に残量表示する。
- split両側の残量をcentral側へ集約表示する機能(peripheral battery proxy/fetching)は、使用するZMKバージョンでのサポート状況を確認してから採用する。

## 今後必要になる成果物

1. **Shield定義**(`firmware/zmk/` 配下、後続フェーズで作成):
   - `Kconfig.shield` / `Kconfig.defconfig`
   - `<shield>.dtsi`(kscan、matrix transform、physical layout)
   - `<shield>_left.overlay` / `<shield>_right.overlay`(GPIO、nice!view SPI)
   - `<shield>.keymap`(初期キーマップ)
   - `<shield>.conf`(スリープ・バッテリー監視等の設定)
2. GitHub ActionsによるZMKビルド設定(zmk-config形式にするかは未確定)

## GPIO割り当て確定後に作業する項目

- [ ] kscan設定(row/col GPIO、diode direction)の記述
- [ ] matrix transformの記述(56キー、左右オフセット)
- [ ] nice!view SPI設定の記述
- [ ] バッテリーADC設定
- [ ] スリープ・省電力設定(LED非搭載のためディスプレイとBLEが主な消費源)
- [ ] 初期キーマップ作成(追加1uキーは汎用キーとして扱う)
- [ ] 実機でのビルド・書き込み・動作確認([bring-up.md](bring-up.md))

## 制約

- Raspberry Pi Pico / RP2040 は使用しない(nRF52840のみ)。
- OLED対応は不要(nice!view専用)。
- 動作確認まで「動作する設定」と表記しない。

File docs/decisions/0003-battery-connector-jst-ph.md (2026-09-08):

# ADR-0003: バッテリーコネクタはJST PH(2.0mm)、S2B-PH-SM4-TB(LF)(SN)

## Status

**Accepted**(2026-09-08 ユーザー承認。**極性は実バッテリー確認まで未確定**)

## Context

左右各1個の2ピンバッテリーコネクタが必要([../product-requirements.md](../product-requirements.md))。薄型構成のため低背であること、手実装可能であること、脱着で消耗しにくいことが求められる。

確認済み情報([../references.md](../references.md)):

- JST PHシリーズ: 2.0mmピッチ、定格2A/100V。公式資料は [ePH.pdf](https://www.jst-mfg.com/product/pdf/eng/ePH.pdf)
- S2B-PH-SM4-TB(LF)(SN): 2ピン・**表面実装・横型(サイドエントリー)**。自作キーボードで最も一般的なバッテリーコネクタ

## Decision

**JST PH 2.0mm、基板側は S2B-PH-SM4-TB(LF)(SN)(SMD横型2ピン)を採用する。**

ただし**ピン極性(+/−の割り当て)は未確定のまま**とし、購入するバッテリー実物のリード極性を確認してから回路図で確定する(市販LiPoのPHコネクタ極性は統一されていないため)。

## Alternatives

| 案 | 概要 | 不採用理由 |
| --- | --- | --- |
| B2B-PH-K-S(スルーホール縦型) | 同PHシリーズの縦型 | 縦型は挿抜方向が上向きになり薄型ケースと相性が悪い。スルーホールは裏面に足が突出し、バッテリー保護要件と干渉しやすい |
| Molex PicoBlade等 1.25mmピッチ | より小型 | 定格・機械強度が小さく、手実装や挿抜に不利。市販LiPoのPH品揃えが最多 |
| 直はんだ(コネクタなし) | 部品削減 | 交換性・組立性が悪く、要件(コネクタ搭載)に反する |

## Consequences

- バッテリーはJST PHコネクタ付きの3.7V LiPoから選定することになる(ADR未定の容量・寸法選定の前提条件)。
- 横型のため、基板端付近に挿抜方向の空間を確保するレイアウト制約が生じる。
- SMDだが端子が大きく手はんだ可能。

## Verification

- 発注前チェックリスト: 基板側フットプリント・シルクの極性表示と、購入バッテリーの実物極性をテスターで照合(bring-up手順3にも組込み済み)。
- フットプリントはJST公式図面(ePH.pdf)と照合してから使用する。

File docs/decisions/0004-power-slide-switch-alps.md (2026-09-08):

# ADR-0004: 電源スライドスイッチはAlps Alpine SSSS811101

## Status

**Accepted**(2026-09-08 ユーザー承認。BOOST不使用・バッテリー500mAh以下方針を含む)

## Context

左右各1個、明確なON/OFF位置を持つ2ポジション式スライドスイッチが必要。ケース側面から操作、突出量を抑える、薄型構成([../product-requirements.md](../product-requirements.md))。

確認済み情報(公式製品ページ、[../references.md](../references.md)):

- **Alps Alpine SSSS811101**: 単極・2ポジション、表面実装、本体6.7×2.6×1.4mm(高さ1.4mm)、アクチュエータ高1.1mm、トラベル1.5mm、動作温度-40〜+85℃
- **定格: 0.3A 5V DC(max)/ 50μA 3V DC(min)**
- ZMK系無線キーボード(Corne等)で広く採用実績がある

## Decision

**Alps Alpine SSSS811101 を採用する。**

付随する重要な制約: 定格0.3Aのため、**nice!nanoのチャージブースト(約500mA充電)は使用しない**。充電は標準の約100mAのみとする。これはバッテリー容量選定(未定ADR)の前提になる(大容量にしても充電が遅いだけでなく、公式もブーストは500mAh超専用としているため、**500mAh以下のバッテリーを選ぶ方針と整合**する)。

## Alternatives

| 案 | 概要 | 不採用理由 |
| --- | --- | --- |
| 汎用SS-12D00系(スルーホール縦型) | 定格に余裕、安価 | 背が高く薄型化に不利。SMD低背で実績のあるSSSS811101を優先 |
| Copal(Nidec)CUS-12TB等 | 同クラスのSMD小型 | 同等候補だが、キーボード用途での採用実績と入手性でSSSS811101を優先。入手難の場合の代替候補として保持 |
| 電源スイッチなし(ソフトOFFのみ) | 部品削減 | 要件(物理2ポジションスイッチ)に反する |

## Consequences

- 挿入位置はBATTERY+ライン直列([../electrical.md](../electrical.md) 候補A)。充電電流(約100mA)+動作電流はスイッチ経由となり、定格0.3A内に収まる。
- **BOOSTジャンパは基板上で使用禁止**(シルクまたはドキュメントで明示)。
- 低背1.4mm+アクチュエータ1.1mmのため、ケース側面開口はノブ位置を精密に合わせる必要がある(機構設計への申し送り)。
- ON/OFF表示はシルクで基板に印字する(要件)。

## Verification

- フットプリントと寸法をAlps公式図面と照合してから使用する(公式ページの寸法表記と流通データの差異があるため、**公式PDF図面の取得・照合を必須**とする)。
- bring-up手順12でON/OFFの確実な断続を実測確認。
- 充電中(USB接続時)のスイッチOFF挙動を実機確認(OFF中は充電されない想定の検証)。

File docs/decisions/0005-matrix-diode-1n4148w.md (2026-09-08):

# ADR-0005: マトリクスダイオードは1N4148W(SOD-123)

## Status

**Accepted**(2026-09-08 ユーザー承認)

## Context

全56キー(片側28)に逆流防止ダイオードが必要。手実装のため、はんだしやすいパッケージが望ましい。

確認済み情報(複数メーカーのデータシート、[../references.md](../references.md)):

- **1N4148W**: 小信号高速スイッチングダイオード、**SOD-123**パッケージ、VR 75V / VRRM 100V、IF 150mA、trr約4ns。複数メーカー(Vishay、Diodes Inc.、MCC等)が製造する定番セカンドソース品

## Decision

**1N4148W(SOD-123)を採用する。** メーカーは入手性で選んでよい(セカンドソース互換)。

## Alternatives

| 案 | 概要 | 不採用理由 |
| --- | --- | --- |
| 1N4148(スルーホール) | 更に手はんだしやすい | 両面に足が出て薄型化・バッテリー保護と干渉。SOD-123は十分手はんだ可能 |
| 1N4148WS / 1N4148WT(SOD-323/523) | より小型 | 手実装の難度が上がる。小型化の必要がない |
| ショットキー(BAT54等) | VF低 | マトリクス用途に利点がなく、リーク電流が大きい |

## Consequences

- キーマトリクス(5V未満・数mA)に対し定格は十分。
- SOD-123はPCB裏面(ソケット面)実装を想定。高さはKailhソケット(1.85mm)より低く、底板クリアランスの支配要因にならない。
- 回路図では全ダイオードの向きをcol2row方針([0002](0002-matrix-and-gpio.md))と一致させる。

## Verification

- フットプリントを採用メーカーのデータシート推奨パッドと照合。
- 発注前チェックリスト: ダイオード方向の全数確認(既存項目)。

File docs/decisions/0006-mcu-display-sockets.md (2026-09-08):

# ADR-0006: nice!nanoはコンスルー実装(第一候補)、nice!viewは2.54mm低背ソケット

## Status

**Accepted**(2026-09-08 ユーザー承認。**具体型番と高さは図面確認後に本ADRを更新**)

## Context

nice!nanoとnice!viewの両方を交換可能なソケット実装にする要件([../product-requirements.md](../product-requirements.md))。積層(nice!viewがnice!nanoの上)のため、各層の高さが機構設計に直結する。

前提(確認済み):

- nice!nanoはPro Micro形状、片側12ピン×2列(2.54mmピッチ)、ミッドマウントUSB-Cで基板厚3.2mm
- nice!viewは5ピン(2.54mmピッチ)

## Decision

1. **nice!nano: コンスルー(Mac8系スプリングピンヘッダ、12ピン×2)を第一候補**とする。
   - nice!nano側へのはんだ付けが不要で、完全に無加工のまま交換できる(交換性が最も高い)
   - 国内(遊舎工房等)で入手性が高く、Helix/Corne系キットでの実績が多い
   - 高さ候補: 2.5mm / 3.5mm(**型番と正確な高さ・対応基板厚は公式図面で確認してから確定**)
2. **nice!view: 2.54mmピッチ5ピンの低背ピンソケット(メスヘッダ)+ nice!view側ピンヘッダ**とする。
   - 高さは、下層のnice!nano上面(コンスルー高+3.2mm)+クリアランスから逆算して選定する(未確定)

## Alternatives

| 案 | 概要 | 不採用理由 |
| --- | --- | --- |
| Mill-Max 315系低背ソケット + マシンピン | 最薄クラスの実績ある方式 | nice!nano側にピンのはんだ付けが必要で交換性が一段落ちる。コンスルー入手難・高さ不適合の場合の**代替候補として保持**(315-43-112-41-003000等) |
| 通常のピンヘッダ+ソケット直付け | 安価 | 背が高く薄型化に反する |
| 直はんだ | 最薄 | 交換可能要件に反する |

## Consequences

- PCBのnice!nano用スルーホールはコンスルー対応(めっきスルーホール、推奨穴径は公式図面確認後に確定)とする。Mill-Max代替でも同じ2.54mmピッチ穴を共用できる見込み(穴径互換は要確認)。
- nice!view装着高はnice!nanoスタックより上になるため、ケース最厚部はこの積層で決まる([../mechanical.md](../mechanical.md))。
- コンスルーの向き・挿抜方法をビルドガイドに記載する必要がある(将来)。

## Verification

- コンスルーの型番・高さ・対応基板厚・推奨穴径をメーカー公式図面(Mac8)で確認し、本ADRを更新してから回路図・フットプリントに反映する。
- 積層高さの計算表を [../mechanical.md](../mechanical.md) に追加し、USB-C開口・ケース高と整合することを確認する。
- Rev.A実機で挿抜・接触安定性を確認(bring-up手順5・9)。

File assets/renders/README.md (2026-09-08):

# assets/renders/

レンダリング画像・写真・図版を置く(まだなし)。READMEやドキュメントから参照する画像はここに集約する。

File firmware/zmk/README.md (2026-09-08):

# firmware/zmk/

ZMKのShield定義・設定を置くディレクトリ。方針は `docs/firmware.md` を参照。

**まだ実装していない。** GPIO割り当てが未確定のため、この段階では動作未確認の完成版ZMK設定を作らない方針(AGENTS.md参照)。

## 今後ここに置くもの

- Shield定義(`Kconfig.shield` / `Kconfig.defconfig` / `.dtsi` / `_left.overlay` / `_right.overlay` / `.keymap` / `.conf`)
- ビルド設定(zmk-config形式にするかは未確定)

## ルール

- ピン割り当てを変更したら、回路図・`docs/electrical.md` のGPIO表と**同時に**更新する。
- キーマップ・matrix transformは `docs/key-layout.md`(片側28キー、物理と論理の分離)と整合させる。

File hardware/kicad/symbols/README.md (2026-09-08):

# symbols/

プロジェクト固有のKiCadシンボルライブラリを置く(まだなし)。外部由来のシンボルは出典・ライセンスを `docs/references.md` に記録すること。

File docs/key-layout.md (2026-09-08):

# キー配列定義(Key Layout)

左半分を基準に定義し、右半分は完全な左右反転とする。

- 全キー1u / 基本キーピッチ19.05mm
- 列スタッガー・キーの回転は使用しない(純粋なオーソリニア格子)
- **片側28キー、左右合計56キー**
- nice!viewはキー数に含めない

## 左半分の概念配置図

```
┌──────────────────────┬───────────┐
│ □  □  □  □  □  □ │           │   R0: C0–C5
│ □  □  □  □  □  □ │ nice!view │   R1: C0–C5
│ □  □  □  □  □  □ │           │   R2: C0–C5
│ □  □  □  □  □  □ │    □ 1u   │   R3: C0–C5 + C6(親指側追加キー)
├───────────┘          └───────────┘
│ □  □  □ │                          R4: C0–C2(小指側下部追加キー)
└───────────┘
```

この図は**概念図**です。実際のnice!view寸法・マイコン寸法・ケース余白に基づく正確な外形は後続フェーズで決定します。

### 基板外形の方針(確定)

**基板外形は全体を覆う長方形にしない。** キーおよびnice!view/nice!nano領域が存在する部分にのみ基板を設け、キーが入らない領域は切り欠く:

- R4行は C0–C2 の3キー分のみ下方向へ張り出す。**その右側(R4×C3–C6に相当する下部領域)には基板を設けない**
- 親指側C6タブは、追加1uキー(R3×C6)とその真上のnice!view/nice!nano占有領域の分だけ張り出す
- 右半分はこの外形の完全ミラー
- 切り欠きの入隅R、ケース余白、正確な輪郭線は後続フェーズで決定する([mechanical.md](mechanical.md))

## 左半分の論理座標

行はR0(最上段)〜R4(最下段)、列はC0(小指側=左端)〜C6(親指側=右端)。
格子座標はキー中心位置を (C × 19.05mm, R × 19.05mm) とする格子に対応する。

| 座標範囲 | キー数 | 説明 |
| --- | --- | --- |
| R0–R3 × C0–C5 | 24 | 基本の4行×6列オーソリニア |
| R4 × C0–C2 | 3 | 小指側(左端3列)のみ下方向へ追加した第5行 |
| R3 × C6 | 1 | 親指側右端に追加した通常の1uキー |

### キー数の計算

```
基本グリッド : 4行 × 6列 = 24キー
小指側第5行 : 3キー (R4×C0–C2)
親指側追加  : 1キー (R3×C6)
--------------------------------
片側合計    : 28キー
左右合計    : 28 × 2 = 56キー
```

### 存在しない座標

R4×C3–C6、R0–R2×C6 にはキーを配置しない。
R0–R2×C6 相当の領域(追加1uキーの真上)には **nice!view を縦向きに配置**する(キーではないためキー数に含めない)。nice!viewの下層にはnice!nanoを積層する(詳細は [mechanical.md](mechanical.md))。

### 追加1uキー(R3, C6)の扱い

Space専用キーではなく、**通常の汎用キー**として扱う。キーキャップ・スイッチ・マトリクス上の扱いは他のキーと同一。

## 右半分のミラー規則

- 右半分は左半分の**物理配置を左右反転(Y軸ミラー)**したもの。
- 論理座標は左半分と同じ R0–R4 / C0–C6 の体系を用い、**C0が小指側(右端)、C6が親指側(左端)**になる。つまり列番号は常に「小指側=C0」で数え、物理座標のみ反転する。
- 右半分では、nice!view(縦向き)と追加1uキーが左端(親指側)に来る。
- 回路をリバーシブルPCBにするか左右別PCBにするかは未確定(ADR予定)。いずれの場合もこの物理ミラー規則を満たすこと。

## ZMKにおける扱い

**物理配置(physical layout)と論理マトリクス(kscan matrix)は分離して考えること。**

- 物理配置: 上記の格子座標(キーの見た目の位置)。ZMKでは physical layout / keymap 表示に対応。
- 論理マトリクス: 電気的な行×列(GPIO割り当てに依存)。28キー片側をどうマトリクス化するかは [electrical.md](electrical.md) で検討中であり、物理の5行×7列とは一致しなくてよい。
- 左右のマトリクス変換(transform)はZMKの matrix transform で吸収する(詳細は [firmware.md](firmware.md))。

## 今後の予定

- 寸法入りのSVGまたはDXF(キー中心座標・外形候補・nice!view/nice!nano占有領域を含む)を後続フェーズで追加する。

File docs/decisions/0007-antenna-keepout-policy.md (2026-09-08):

# ADR-0007: アンテナ禁止領域の設計方針

## Status

**Accepted**(2026-09-08 ユーザー承認。寸法は暫定値であり、Rev.A実測で検証する)

## Context

nice!nanoのnRF52840はオンボードアンテナ(USB-Cと反対側の基板端)でBLE通信する。要件としてアンテナ禁止領域の確保が必要だが、**nice!nano公式ドキュメントにはkeep-out推奨寸法の記載がない**([../references.md](../references.md))。

一般的な2.4GHz PCBアンテナの設計指針(非公式の一般則):

- アンテナ直下は全層で銅箔(ベタGND・配線・ビア)を除去する
- アンテナ同一層で15mm程度、他層で6mm以上のクリアランスが目安とされる
- 金属部品・バッテリー・ねじ等の金属をアンテナ近傍に置かない

## Decision

以下を設計ルールとする(暫定値):

1. **nice!nanoはアンテナ端をキーボード外周側(基板端)へ向けて配置**する。可能ならアンテナ部を基板端ぎりぎりに寄せ、母板がアンテナの先に延びない配置を優先する。
2. 母板上の**アンテナ投影領域+周囲5mm以上**を全層keep-out(銅箔・配線・ビア・部品・ねじ穴禁止)とする。アンテナ先方向は基板端まで開放する。
3. **バッテリー・金属プレート・ねじ・スペーサーはkeep-out領域とその上下空間に配置しない**([../mechanical.md](../mechanical.md) の非金属化要件と連動)。
4. アンテナ投影領域の正確な位置・幅は、nice!nano公式ピン配置図・実測から起こした検証済みフットプリントで定義する。

## Alternatives

| 案 | 概要 | 不採用理由 |
| --- | --- | --- |
| アンテナ部を母板から完全にオーバーハングさせる | 電気的に最良 | 外形・ケース設計の制約が増える。基板端配置+keep-outで十分と判断(Rev.Aで実測検証) |
| keep-outなし(ベタGNDをアンテナ下まで) | 配線が楽 | 2.4GHzアンテナの一般則に明確に反し、BLE性能劣化のリスク大 |
| 15mm以上の大型keep-out | より保守的 | C6タブ周辺の面積制約と衝突。5mm+基板端開放を暫定とし、実測で不足なら拡大 |

## Consequences

- nice!nano配置は「アンテナ=外周向き」が確定し、PCBレイアウトの初期条件になる。USB-C(反対側)はキー領域側を向くため、**USB-Cケーブルの取り回しとケース開口方向は機構設計で要検討**。
- keep-out領域はKiCadのrule area(全層)として定義し、DRCで機械的に検証できるようにする。

## Verification

- 設計チェックリスト: keep-out領域に銅箔・部品・ねじ穴がないこと(既存項目)。
- bring-up手順10-11: 左右間・ホスト間BLEの接続距離を実測し、実用性能(同室内で安定接続)を確認。不足ならRev.Bでkeep-out拡大またはオーバーハング化。
- 参考にした一般則は非公式のため、より信頼できる参考設計(FelixKeeb等の実績あるnice!nanoボード)のkeep-out実例を確認したら本ADRに追記する。

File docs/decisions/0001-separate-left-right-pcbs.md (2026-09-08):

# ADR-0001: Rev.Aは左右別PCB(リバーシブルPCBを採用しない)

## Status

**Accepted**(2026-09-08 ユーザー承認)

## Context

左右分割キーボードのPCBには2方式ある:

1. **リバーシブルPCB**: 1種類の基板を裏返して左右両方に使う(Helix、初期Corne等で採用)
2. **左右別PCB**: 左用・右用を別々に設計する

本プロジェクトの制約([../product-requirements.md](../product-requirements.md)):

- 右半分は左半分の完全な左右反転
- Kailh MXホットスワップソケット(PCB裏面実装)
- nice!nano + nice!view をソケットで積層(R3C6の真上、非対称な占有領域)
- アンテナ禁止領域の確保
- Rev.AはPCBのみ発注・手実装

## Decision

**Rev.Aは左右別PCB(2種類)とする。** 右基板は左基板のミラーとしてKiCad上で生成し、以後は左を正として同期する。

## Alternatives

| 案 | 概要 | 不採用理由 |
| --- | --- | --- |
| リバーシブルPCB | 1設計を両面使いして左右共用。発注が1種類で済み、面あたり単価が下がる | ホットスワップソケットは裏面実装のため、リバーシブル化には両面対応フットプリント(重ねパッド)や両面実装が必要になり、フットプリント検証の難度と手実装ミスのリスクが上がる。nice!view/nice!nano積層部・スライドスイッチ・JSTも両面対応が必要。シルク表記も両面兼用になり、初号機の目視検査(bring-up手順1)が難しくなる。アンテナ禁止領域も両向きで成立させる必要がある |
| 片側共通+ジャンパ切替 | 1基板+はんだジャンパで左右を切替 | リバーシブルと同様の複雑さに加えてジャンパ設定ミスのリスクが増える |

## Consequences

- 良い点: 各基板の設計・フットプリント・シルクが単純になり、Rev.Aの検証項目が減る。標準的なKailhソケットフットプリントをそのまま使える。目視検査・手実装が容易。
- 悪い点: 発注が2種類になり最小発注数の関係で割高・余剰基板が増える。左右の設計同期を人手で保証する必要がある(左を正とし、右の再ミラー手順をルール化して緩和。検証チェックリストに左右反転整合の項目あり)。
- 波及: [../manufacturing.md](../manufacturing.md) の発注枚数計画、`hardware/kicad/` のプロジェクト構成(左右2ボード)、[../verification-checklist.md](../verification-checklist.md) の「左右別PCBの場合」の分岐が確定する。

## Verification

- KiCad設計時: 右基板が左基板のミラーであることをネットリスト比較・目視で確認(設計チェックリスト)。
- Rev.A評価で左右差に起因する問題(部品調達・組立効率)が大きければ、Rev.BでリバーシブルPCBを再検討する。

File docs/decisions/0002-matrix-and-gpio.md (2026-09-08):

# ADR-0002: マトリクスは物理一致の5行×7列、GPIO割り当てはZMK標準準拠

## Status

**Accepted**(2026-09-08 ユーザー承認)

## Context

片側28キー(物理配置は4×6+3+1、[../key-layout.md](../key-layout.md))をスキャンするマトリクス配線と、nice!nano v2のGPIO割り当てを決める必要がある。

前提(公式資料確認済み、[../references.md](../references.md)):

- nice!nano v2のヘッダー使用可能GPIOは18本
- バッテリー残量はVDDH測定のためADC用GPIO不要
- ZMK公式のnice!view標準ピンは CS=D1、MOSI=D2、SCK=D3

## Decision

1. **マトリクスは物理配置に沿った行線5本(R0–R4)+列線7本(C0–C6)= GPIO 12本**とする。35交点のうちキーのない7交点(R0–R2×C6、R4×C3–C6)にはスイッチ・ダイオードを置かない。
2. **GPIO割り当て**(左右共通):

| 用途 | ピン |
| --- | --- |
| nice!view CS / MOSI / SCK | D1(P0.06)/ D2(P0.17)/ D3(P0.20)— ZMK標準 |
| Row0–Row4 | D4(P0.22)、D5(P0.24)、D6(P1.00)、D7(P0.11)、D8(P1.04) |
| Col0–Col6 | D9(P1.06)、D10(P0.09)、D16(P0.10)、D14(P1.11)、D15(P1.13)、D18(P1.15)、D19(P0.02) |
| 予備(テストパッド候補) | D0(P0.08)、D20(P0.29)、D21(P0.31) |

3. diode directionは **col2row を第一候補**とする(kscan設定確定時に回路図と同時レビュー)。

## Alternatives

| 案 | 概要 | 不採用理由 |
| --- | --- | --- |
| 4行×7列への詰め替え(11 GPIO) | 追加行R4の3キーを電気的に別行へ折り込みGPIOを1本節約 | GPIOに余裕があり節約の必要がない。物理と電気の座標がズレて配線が交差し、手実装・デバッグ時の追跡性が下がる |
| nice!viewを独自ピンに配置 | 配線自由度が上がる | ZMK標準(`nice_view_adapter`)から外れ、shield定義の流用性が下がる |

## Consequences

- 良い点: 基板配線が物理配置と一致し、テスターでの検証・bring-upが容易。ZMKのnice!view関連設定を標準のまま使える。予備3ピンをテストパッドに回せる。
- 悪い点: 4×7比でGPIOを1本多く使う(実害なし)。
- 注意: **PCB配線の都合でRow/Col個別ピンの入れ替えはあり得る**。その場合は回路図・[../electrical.md](../electrical.md) のGPIO表・ZMK設定を同時更新する(AGENTS.mdルール)。nice!viewの3ピンは標準維持のため入れ替え対象外。
- 波及: [../electrical.md](../electrical.md)(GPIO表確定)、[../firmware.md](../firmware.md)(kscan/transform作業が着手可能に)。

## Verification

- D10(P0.09)/D16(P0.10)はNFC兼用ピン。nice!nanoボード定義でGPIO化されていること(nfct-pins-as-gpios相当)をZMKビルド時に確認する([../references.md](../references.md) 未確認#10)。
- 回路図完成時、ダイオード方向とkscan設定の一致をレビュー(設計チェックリスト)。
- bring-up手順7–8(単キー→全キーマトリクス)で実機検証する。

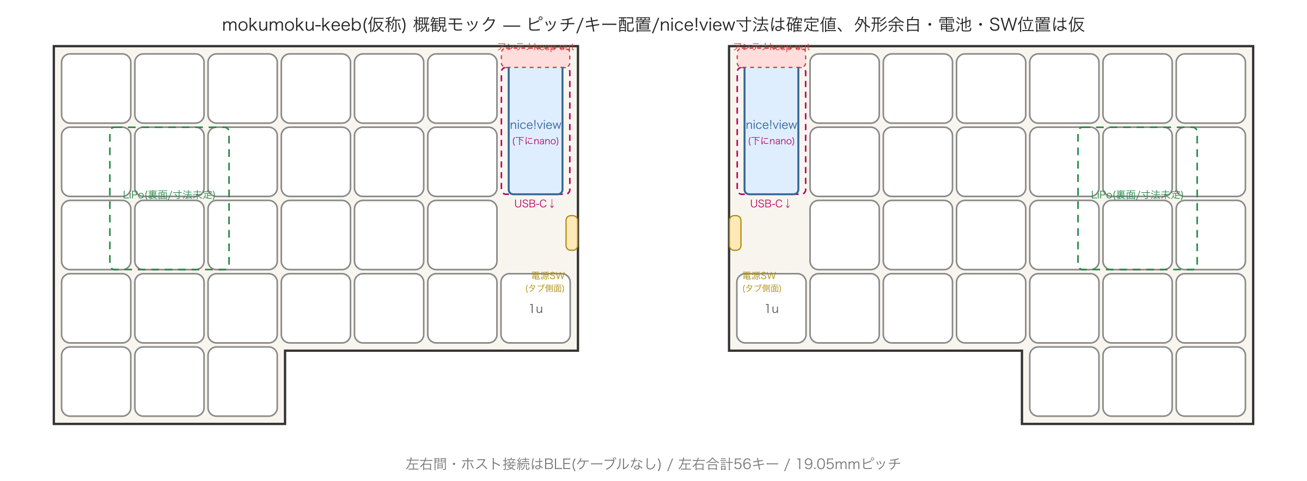
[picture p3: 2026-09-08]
assets/renders/concept-layout.png

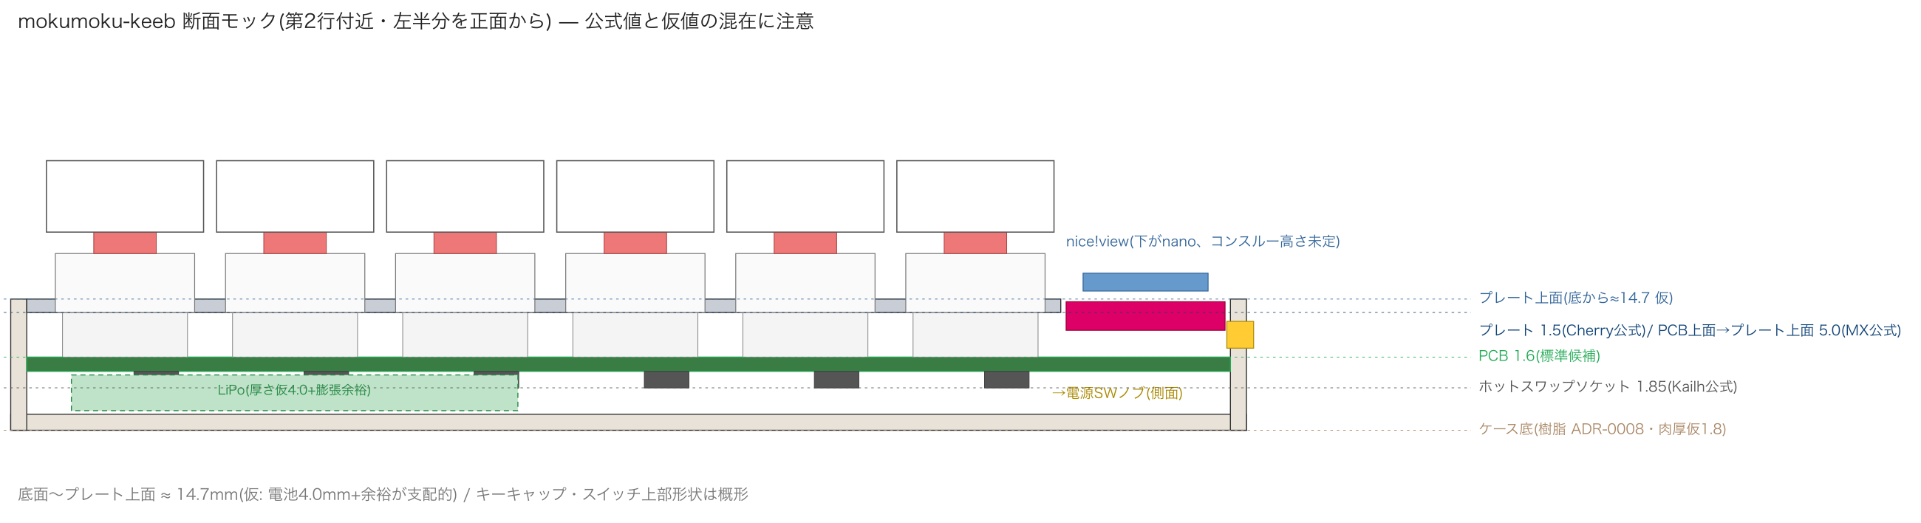
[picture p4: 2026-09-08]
assets/renders/concept-side.png

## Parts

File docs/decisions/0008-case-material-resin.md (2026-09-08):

# ADR-0008: ケースはフル樹脂削り出し方針(POM/PC候補)

## Status

**Accepted**(2026-09-08 ユーザー承認。「いったん」の方針決定であり、Rev.B以降での再検討余地を明記)

## Context

ケースを削り出しで製作したい意向がある一方、本機は完全無線(BLE)であり、
アンテナ周辺の金属はADR-0007のkeep-out方針および要件(アンテナ周辺の非金属化)と衝突する。

検討した構成:

1. アルミ筐体+アンテナ部のみ樹脂窓 — 質感・剛性は最良だが加工が複雑、RF検証前に金属範囲を確定するリスク
2. アルミ+樹脂のハイブリッド(例: アルミボトム+樹脂トップ) — 妥協点だが接合設計が増える
3. **フル樹脂削り出し(POM / ポリカーボネート等)** — RF問題が原理的に発生しない、加工も単純

## Decision

**ケースはフル樹脂の削り出しを基本方針とする。** 材質はPOM / PCを第一候補群とし、具体材質・色は未確定。

進め方: PCBレイアウト確定 → **3Dプリントで試作ケース**(干渉・開口・BLE実測の検証)→ 問題なければ樹脂削り出しを発注。

## Alternatives

| 案 | 不採用理由 |
| --- | --- |
| フルアルミ | アンテナを金属で囲いBLE性能を大きく損なう(要件違反) |
| アルミ+樹脂窓 | Rev.Aでのアンテナ実測前に金属範囲を決めるのはリスクが大きい。**Rev.B以降、実測結果を踏まえて再検討可**(その場合は本ADRをSupersede) |

## Consequences

- ケース起因のRF制約が消えるため、ケース設計の自由度が上がる(アンテナ直上の開口・薄肉化が不要)。
- プレート材質(未確定)は引き続きアンテナ上方の非金属化ルールに従う(金属プレート採用時はアンテナ部切り欠き)。
- CADはCadQuery等のスクリプト生成を基本とし、PCB外形データに追従させる([../mechanical.md](../mechanical.md))。
- 発注データ(STEP・図面・材質仕様)は `production/<revision>/` に凍結する。

## Verification

- 3Dプリント試作で: 部品干渉、USB-C/スライドSW/リセット開口、打鍵時の剛性、バッテリー収納・膨張余裕を確認。
- bring-up手順10-11のBLE実測(ケース装着状態でも確認)。
- 削り出し発注前に、工具径由来の内隅R・最小肉厚・公差をベンダーのDFMガイドと照合。

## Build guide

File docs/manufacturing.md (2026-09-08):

# 製造方針(Manufacturing)

**現在はまだ発注可能な状態ではない。** 回路図・PCBが存在せず、製造前検証も未実施。

## Rev.Aの方針

- **Rev.AはPCBのみを発注し、手実装する。**
  - ケース・プレートの発注はRev.A評価後(または並行検討だが、初回発注には含めない)。
  - 部品(ダイオード、ソケット、JST、スライドスイッチ等)は別途調達し手はんだ。
- Rev.Aの評価結果を [revisions/rev-a.md](revisions/rev-a.md) に記録し、必要ならRev.Bで修正する。
- 左右別PCBかリバーシブルPCBかは未確定(ADRで比較・提案予定)。発注枚数・費用に影響する。

## 製造データの配置場所

| データ | 場所 |
| --- | --- |
| KiCadソース(編集可能) | `hardware/kicad/` |
| Gerber・ドリル | `production/rev-a/gerbers/` |
| BOM | `production/rev-a/bom/` |
| 座標データ(CPL) | `production/rev-a/placement/` |

- **製造データは `production/<revision>/` へ凍結保存する。** 発注に使った実データのスナップショットであり、発注後は編集しない。修正は次リビジョン(`production/rev-b/` 等)として作成する。
- 生成物を `hardware/` 配下に置かない(ソースと生成物の分離。AGENTS.md参照)。

## 発注前に必要な検証

[verification-checklist.md](verification-checklist.md) の「製造前チェックリスト」がすべて完了していること。特に:

1. ERC / DRC がエラーなしで通ること
2. 全フットプリントが実部品データシートと照合済みであること(未検証フットプリントの使用禁止)
3. JST極性・ダイオード方向・左右反転・アンテナ禁止領域の確認
4. 製造業者のデザインルール(最小パターン幅・ドリル径等)との整合確認
5. 発注仕様(板厚・層数・表面処理等)の明文化

## 未確定の製造条件

- PCB厚(1.6mm標準候補 / 1.2mmは検証後判断)
- 層数(2層を第一候補とするが、配線検討後に確定)
- 表面処理・レジスト色・シルク内容
- 発注先の製造業者
- 発注枚数(左右別PCBかリバーシブルかに依存)

## 表現に関するルール

製造前チェックリストが完了するまで、このリポジトリ内で「製造可能」「production-ready」「検証済み」と表記しない(AGENTS.md参照)。

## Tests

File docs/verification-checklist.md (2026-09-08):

# 検証チェックリスト(Verification Checklist)

設計 / 製造前 / 組立後 の3段階。**すべての製造前チェックが完了するまで「production-ready」と表記しない。**

## 1. 設計チェックリスト(回路図・PCB作成中〜完了時)

- [ ] キー配列が [key-layout.md](key-layout.md) と一致している(片側28キー、R0–R3×C0–C5 + R4×C0–C2 + R3×C6)
- [ ] 右半分が左半分の完全な左右反転になっている
- [ ] 全キーにダイオードがあり、方向がマトリクス全体で一貫している
- [ ] GPIO表・回路図・ZMK設定のピン割り当てが一致している
- [ ] nice!view(5ピンSPI)の配線が公式ピン配置と一致している
- [ ] nice!nano・nice!viewがソケット実装になっている
- [ ] 電源スライドスイッチ・リセットボタン・JSTコネクタが左右両方にある
- [ ] JST極性が使用予定バッテリーの公式資料と一致している
- [ ] アンテナ禁止領域に銅箔(全層)・部品・ねじ穴がない
- [ ] nice!view装着状態でUSB-C・リセット・スライドスイッチが操作可能な配置である
- [ ] 使用した全フットプリントが実部品データシートと照合済み(照合記録あり)
- [ ] 外部設計を参考にした箇所の出典・ライセンスが [references.md](references.md) に記録されている
- [ ] ERCがエラーなしで通る
- [ ] DRCがエラーなしで通る

## 2. 製造前チェックリスト(発注直前)

- [ ] 設計チェックリストがすべて完了している
- [ ] 未確定事項([product-requirements.md](product-requirements.md))のうち、発注に影響する項目がすべて確定・ADR記録済み
- [ ] PCB厚・層数・表面処理などの発注仕様が明文化されている
- [ ] 製造業者のデザインルールでDRCを再実行しエラーなし
- [ ] Gerber・ドリルデータをビューアで目視確認した(層ずれ・欠落・鏡像違いがない)
- [ ] 左右別PCBの場合: 両方のGerberが揃っている / リバーシブルの場合: 両面使用の整合を確認した
- [ ] BOM・座標データ(必要な場合)が実部品型番と一致している
- [ ] 製造データ一式を `production/rev-a/` に凍結した
- [ ] 発注内容(枚数・仕様・費用)をユーザーが承認した

## 3. 組立後チェックリスト(手実装後)

- [ ] [bring-up.md](bring-up.md) の手順1〜15を順番に実施し、結果を記録した
- [ ] 左右両方で実施した
- [ ] 全56キーの入力を確認した
- [ ] バッテリー駆動・充電・スライドスイッチ断を確認した
- [ ] BLE接続性(左右間・ホスト間)を実使用距離で確認した
- [ ] スリープ時消費電流を実測・記録した
- [ ] NG項目・改善点を [revisions/rev-a.md](revisions/rev-a.md) に記録した
- [ ] Rev.Bが必要か判断し、必要ならADRを起票した

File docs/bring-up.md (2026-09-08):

# 初号機(Rev.A)Bring-up手順

Rev.A(PCBのみ発注・手実装)の動作確認手順。**必ずこの順序で実施**し、結果を [revisions/rev-a.md](revisions/rev-a.md) に記録する。

前提: 手実装が完了していること。ただし**バッテリーとnice!nanoは接続しない状態から開始**する。

## 手順

1. **目視検査**
   - はんだブリッジ、未はんだ、部品の向き(ダイオード極性、JST極性、ソケット方向)を全数確認
2. **電源短絡確認**(無通電)
   - テスターでVCC–GND間、VBAT–GND間の短絡がないことを確認
3. **JST極性確認**
   - 使用するバッテリー実物の極性と基板側シルク・配線が一致することをテスターで確認(**接続前に必ず**)
4. **USB給電**
   - バッテリー未接続のままnice!nanoをソケットに装着し、USB-Cから給電。発熱・異臭がないこと
5. **マイコン認識**
   - ホストPCがnice!nano(ブートローダ)を認識すること
6. **ZMK書き込み**
   - ビルド済みZMKファームウェアを書き込み、起動すること
7. **単キー入力確認**
   - 任意の1キーにスイッチを挿し、USB接続で入力されること(ホットスワップソケットの導通確認を兼ねる)
8. **全キーマトリクス確認**
   - 全28キー(片側ずつ)が正しいキーコードで入力されること。同時押しでゴーストがないこと
9. **nice!view確認**
   - nice!viewをソケットに装着し、表示されること
10. **左右無線接続**
    - 左右をペアリングし、peripheral側の入力がcentral経由でホストに届くこと
11. **ホストとのBluetooth接続**
    - USBを外し、BLEのみでホストへ入力できること
12. **バッテリー駆動**
    - (手順3完了後)バッテリーを接続し、スライドスイッチONでUSBなしに動作すること。スイッチOFFで確実に停止すること
13. **充電確認**
    - バッテリー接続状態でUSB-Cを挿し、充電されること(電圧上昇または充電表示で確認)
14. **スリープ時消費電力**
    - アイドル→スリープ遷移後の消費電流を測定し、記録する(目標値は未設定。実測値を基準化する)
15. **ケース干渉確認**
    - ケース(または外形モック)と、USB-C・リセット・スライドスイッチ・nice!view・バッテリーの干渉がないこと

## 記録

- 各手順の結果(OK / NG / 条件付きOK)と気づきを [revisions/rev-a.md](revisions/rev-a.md) に記録する。
- NG項目はRev.Bの修正候補としてADR化を検討する。
- 左右両方について実施する(リバーシブルPCBの場合も両面それぞれ確認)。

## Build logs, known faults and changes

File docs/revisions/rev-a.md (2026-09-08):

# Rev.A 記録

初号機(Rev.A)の設計・製造・評価の記録。

- 方針: **PCBのみを発注し、手実装する**([../manufacturing.md](../manufacturing.md))
- ステータス: **未着手**(設計前。回路図・PCB未作成、発注不可の状態)

## 設計スナップショット

(PCB設計完了時に記入: KiCadソースのコミット、`production/rev-a/` への凍結日、発注仕様)

## Bring-up結果

[../bring-up.md](../bring-up.md) の手順に沿って記録する。

| # | 項目 | 左 | 右 | メモ |
| --- | --- | --- | --- | --- |
| 1 | 目視検査 | – | – | |
| 2 | 電源短絡確認 | – | – | |
| 3 | JST極性確認 | – | – | |
| 4 | USB給電 | – | – | |
| 5 | マイコン認識 | – | – | |
| 6 | ZMK書き込み | – | – | |
| 7 | 単キー入力確認 | – | – | |
| 8 | 全キーマトリクス確認 | – | – | |
| 9 | nice!view確認 | – | – | |
| 10 | 左右無線接続 | – | – | |
| 11 | ホストBluetooth接続 | – | – | |
| 12 | バッテリー駆動 | – | – | |
| 13 | 充電確認 | – | – | |
| 14 | スリープ時消費電力 | – | – | 実測値: |
| 15 | ケース干渉確認 | – | – | |

## 発見した問題・Rev.Bへの申し送り

(評価後に記入。必要ならADRを起票)

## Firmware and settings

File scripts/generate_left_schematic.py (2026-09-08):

#!/usr/bin/env python3
"""Generate the left-half schematic (hardware/kicad/left/) from the design data
in ADR-0002 (matrix/GPIO) and docs/key-layout.md.

The schematic is the generated artifact; this script is the editable source.
If pins or the matrix change, update ADR-0002/electrical.md and this script
together (AGENTS.md rule), then re-run.

Usage:  python3 scripts/generate_left_schematic.py
Requires KiCad 9 installed (symbol libraries are copied from the app bundle).
"""

import re
import sys
import uuid
from pathlib import Path

REPO = Path(__file__).resolve().parent.parent
OUT_DIR = REPO / "hardware" / "kicad" / "left"
PROJECT = "mokumoku_keeb_left"
KICAD_SYMBOL_DIR = Path.home() / "Applications/KiCad/KiCad.app/Contents/SharedSupport/symbols"
PROJECT_LIB = REPO / "hardware" / "kicad" / "symbols" / "mokumoku_keeb.kicad_sym"

# --- Design data (must match ADR-0002 / docs/key-layout.md) ---------------
ROWS = 5
COLS = 7
# (row, col) positions that have a key: R0-R3 x C0-C5, R4 x C0-C2, R3 x C6
KEYS = [(r, c) for r in range(4) for c in range(6)] + [(4, c) for c in range(3)] + [(3, 6)]
assert len(KEYS) == 28

# nice!nano pin number (per project symbol) -> net label
NANO_NETS = {
    1: "NV_CS",     # D1/P0.06
    2: None,        # D0/P0.08  spare
    3: "GND", 4: "GND",
    5: "NV_MOSI",   # D2/P0.17
    6: "NV_SCK",    # D3/P0.20
    7: "ROW0",      # D4/P0.22
    8: "ROW1",      # D5/P0.24
    9: "ROW2",      # D6/P1.00
    10: "ROW3",     # D7/P0.11
    11: "ROW4",     # D8/P1.04
    12: "COL0",     # D9/P1.06
    13: "COL1",     # D10/P0.09
    14: "COL2",     # D16/P0.10
    15: "COL3",     # D14/P1.11
    16: "COL4",     # D15/P1.13
    17: "COL5",     # D18/P1.15
    18: "COL6",     # D19/P0.02
    19: None,       # D20/P0.29 spare
    20: None,       # D21/P0.31 spare
    21: "VCC",
    22: "RST",
    23: "GND",
    24: "BAT_SW",   # RAW/B+ (battery via slide switch)
}

# --- Minimal s-expression parsing ----------------------------------------


def tokenize(text):
    return re.findall(r'"(?:[^"\\]|\\.)*"|[()]|[^\s()"]+', text)


def parse(tokens, i=0):
    assert tokens[i] == "("
    i += 1
    out = []
    while tokens[i] != ")":
        if tokens[i] == "(":
            node, i = parse(tokens, i)
            out.append(node)
        else:
            out.append(tokens[i])
            i += 1
    return out, i + 1


def find_all(node, head):
    return [x for x in node if isinstance(x, list) and x and x[0] == head]


def find_one(node, head):
    hits = find_all(node, head)
    return hits[0] if hits else None


def unq(s):
    return s[1:-1] if isinstance(s, str) and s.startswith('"') else s


def extract_symbol(lib_file, name):
    """Return (raw_text, pins) for a symbol; pins = {number: (x, y)} in
    symbol-local coordinates (y up)."""
    text = lib_file.read_text()
    marker = f'(symbol "{name}"'
    start = text.index(marker)
    depth = 0
    for i in range(start, len(text)):
        if text[i] == "(":
            depth += 1
        elif text[i] == ")":
            depth -= 1
            if depth == 0:
                raw = text[start : i + 1]
                break
    node, _ = parse(tokenize(raw))
    pins = {}
    for sub in find_all(node, "symbol") + [node]:
        for pin in find_all(sub, "pin"):
            at = find_one(pin, "at")
            num = unq(find_one(pin, "number")[1])
            pins[num] = (float(at[1]), float(at[2]))
    return raw, pins


def rotated(vec, rot):
    """Symbol-local (y up) -> schematic offset (y down) for rotation rot."""
    lx, ly = vec
    x, y = lx, -ly  # to y-down axes
    for _ in range(rot // 90):
        x, y = y, -x  # visual CCW rotation in y-down coords
    return x, y


def pin_abs(pos, rot, local):
    dx, dy = rotated(local, rot)
    return (round(pos[0] + dx, 4), round(pos[1] + dy, 4))


# --- Schematic emission ---------------------------------------------------

ROOT_UUID = str(uuid.uuid4())
body = []
ref_counters = {}


def u():
    return str(uuid.uuid4())


def next_ref(prefix):
    ref_counters[prefix] = ref_counters.get(prefix, 0) + 1
    return f"{prefix}{ref_counters[prefix]}"


# footprint assignment per reference prefix (docs: footprints/README.md)
FOOTPRINTS = {
    "SW_MX": "mokumoku_keeb:SW_MX_HotSwap_Kailh_PG151101S11_1u",
    "D": "Diode_SMD:D_SOD-123",
    "U1": "mokumoku_keeb:nice_nano_v2",
    "J1": "Connector_JST:JST_PH_S2B-PH-SM4-TB_1x02-1MP_P2.00mm_Horizontal",
    "J2": "Connector_PinHeader_2.54mm:PinHeader_1x05_P2.54mm_Vertical",
    # SW29 (SSSS811101) / SW30 (reset): no verified footprint yet -> empty
}


def place(lib_id, pos, rot, ref, value, pins, extra_props="", footprint=""):
    pin_lines = "\n".join(f'    (pin "{n}" (uuid "{u()}"))' for n in sorted(pins, key=lambda s: (len(s), s)))
    body.append(f'''  (symbol (lib_id "{lib_id}") (at {pos[0]} {pos[1]} {rot}) (unit 1)
    (exclude_from_sim no) (in_bom yes) (on_board yes) (dnp no)
    (uuid "{u()}")
    (property "Reference" "{ref}" (at {pos[0]} {pos[1] - 5.08} 0)
      (effects (font (size 1.27 1.27))))
    (property "Value" "{value}" (at {pos[0]} {pos[1] + 5.08} 0)
      (effects (font (size 1.27 1.27))))
    (property "Footprint" "{footprint}" (at {pos[0]} {pos[1]} 0)
      (effects (font (size 1.27 1.27)) (hide yes)))
    (property "Datasheet" "" (at {pos[0]} {pos[1]} 0)
      (effects (font (size 1.27 1.27)) (hide yes)))
    (property "Description" "" (at {pos[0]} {pos[1]} 0)
      (effects (font (size 1.27 1.27)) (hide yes))){extra_props}
{pin_lines}
    (instances (project "{PROJECT}"
      (path "/{ROOT_UUID}" (reference "{ref}") (unit 1))))
  )''')


def glabel(text, pos, rot, shape="input"):
    body.append(f'''  (global_label "{text}" (shape {shape}) (at {pos[0]} {pos[1]} {rot}) (fields_autoplaced yes)
    (effects (font (size 1.27 1.27)) (justify {"left" if rot in (0,) else "right" if rot == 180 else "left"}))
    (uuid "{u()}")
    (property "Intersheetrefs" "${{INTERSHEET_REFS}}" (at {pos[0]} {pos[1]} 0)
      (effects (font (size 1.27 1.27)) (hide yes)))
  )''')


def wire(p1, p2):
    body.append(f'''  (wire (pts (xy {p1[0]} {p1[1]}) (xy {p2[0]} {p2[1]}))
    (stroke (width 0) (type default)) (uuid "{u()}"))''')


def no_connect(pos):
    body.append(f'  (no_connect (at {pos[0]} {pos[1]}) (uuid "{u()}"))')


def text_note(s, pos, size=1.27):
    body.append(f'''  (text "{s}" (exclude_from_sim no) (at {pos[0]} {pos[1]} 0)
    (effects (font (size {size} {size})) (justify left bottom)) (uuid "{u()}"))''')


def main():
    if not KICAD_SYMBOL_DIR.exists():
        sys.exit(f"KiCad symbol dir not found: {KICAD_SYMBOL_DIR}")

    libs = {}
    wanted = [
        ("Switch", "SW_Push"),
        ("Switch", "SW_SPDT"),
        ("Device", "D"),
        ("Connector_Generic", "Conn_01x02"),
        ("Connector_Generic", "Conn_01x05"),
        ("power", "GND"),
        ("power", "VCC"),
        ("power", "PWR_FLAG"),
    ]
    for libname, sym in wanted:
        raw, pins = extract_symbol(KICAD_SYMBOL_DIR / f"{libname}.kicad_sym", sym)
        raw = raw.replace(f'(symbol "{sym}"', f'(symbol "{libname}:{sym}"', 1)
        libs[f"{libname}:{sym}"] = (raw, pins)
    raw, pins = extract_symbol(PROJECT_LIB, "nice_nano_v2")
    raw = raw.replace('(symbol "nice_nano_v2"', '(symbol "mokumoku_keeb:nice_nano_v2"', 1)
    libs["mokumoku_keeb:nice_nano_v2"] = (raw, pins)

    sw_pins = libs["Switch:SW_Push"][1]
    d_pins = libs["Device:D"][1]

    # --- Key matrix cells (physical grid layout, col2row) ---
    X0, Y0, PITCH_X, PITCH_Y = 63.5, 38.1, 30.48, 33.02
    for (r, c) in KEYS:
        cx, cy = X0 + c * PITCH_X, Y0 + r * PITCH_Y
        ref = next_ref("SW")
        place("Switch:SW_Push", (cx, cy), 0, ref, "MX", sw_pins, footprint=FOOTPRINTS["SW_MX"])
        p1 = pin_abs((cx, cy), 0, sw_pins["1"])
        p2 = pin_abs((cx, cy), 0, sw_pins["2"])
        glabel(f"COL{c}", p1, 180)
        # diode below-right of the switch, cathode down toward ROW label
        dref = next_ref("D")
        drot = 90 if rotated(d_pins["2"], 90)[1] < 0 else 270  # anode up
        anode_target = (p2[0], p2[1] + 2.54)
        dx, dy = rotated(d_pins["2"], drot)
        dpos = (round(anode_target[0] - dx, 4), round(anode_target[1] - dy, 4))
        place("Device:D", dpos, drot, dref, "1N4148W", d_pins, footprint=FOOTPRINTS["D"])
        wire(p2, anode_target)
        kath = pin_abs(dpos, drot, d_pins["1"])
        row_pt = (kath[0], kath[1] + 2.54)
        wire(kath, row_pt)
        glabel(f"ROW{r}", row_pt, 270)

    # --- nice!nano ---
    nano_pins = libs["mokumoku_keeb:nice_nano_v2"][1]
    npos = (285.75, 190.5)
    place("mokumoku_keeb:nice_nano_v2", npos, 0, "U1", "nice!nano v2", nano_pins, footprint=FOOTPRINTS["U1"])
    for num, net in NANO_NETS.items():
        pt = pin_abs(npos, 0, nano_pins[str(num)])
        left_side = nano_pins[str(num)][0] < 0
        if net is None:
            no_connect(pt)
        elif net == "GND":
            grot = 0  # place GND power symbol via label instead
            glabel("GND", pt, 180 if left_side else 0)
        else:
            glabel(net, pt, 180 if left_side else 0)

    # --- battery connector + slide switch (support section) ---
    jst_pins = libs["Connector_Generic:Conn_01x02"][1]
    jpos = (63.5, 215.9)
    place("Connector_Generic:Conn_01x02", jpos, 0, "J1", "JST_PH_S2B-PH-SM4-TB", jst_pins, footprint=FOOTPRINTS["J1"])
    j1 = pin_abs(jpos, 0, jst_pins["1"])
    j2 = pin_abs(jpos, 0, jst_pins["2"])
    # NOTE: polarity TBD (ADR-0003) - pin1=BAT+ assumed until battery verified
    glabel("BAT_PLUS", j1, 180)
    glabel("GND", j2, 180)
    text_note("JST PH polarity ASSUMED pin1=+ / pin2=- : VERIFY against real battery before fab (ADR-0003)", (40.64, 227.0))

    sp_pins = libs["Switch:SW_SPDT"][1]
    spos = (114.3, 215.9)
    place("Switch:SW_SPDT", spos, 0, "SW29", "SSSS811101", sp_pins)
    common = pin_abs(spos, 0, sp_pins["2"])
    throw_a = pin_abs(spos, 0, sp_pins["1"])
    throw_b = pin_abs(spos, 0, sp_pins["3"])
    glabel("BAT_PLUS", common, 180)
    glabel("BAT_SW", throw_a, 0)
    no_connect(throw_b)
    text_note("Power switch in BATTERY+ line. 0.3A rating: never bridge nice!nano BOOST jumper (ADR-0004)", (40.64, 231.0))

    # --- reset switch ---
    rpos = (165.1, 215.9)
    place("Switch:SW_Push", rpos, 0, "SW30", "RESET", sw_pins)
    r1 = pin_abs(rpos, 0, sw_pins["1"])
    r2 = pin_abs(rpos, 0, sw_pins["2"])
    glabel("RST", r1, 180)
    glabel("GND", r2, 0)

    # --- nice!view connector (pin order per official pinout: MOSI SCK VCC GND CS) ---
    nv_pins = libs["Connector_Generic:Conn_01x05"][1]
    vpos = (215.9, 215.9)
    place("Connector_Generic:Conn_01x05", vpos, 0, "J2", "nice_view", nv_pins, footprint=FOOTPRINTS["J2"])
    nv_nets = {"1": "NV_MOSI", "2": "NV_SCK", "3": "VCC", "4": "GND", "5": "NV_CS"}
    for num, net in nv_nets.items():
        glabel(net, pin_abs(vpos, 0, nv_pins[num]), 180)

    # --- PWR_FLAGs (BAT_PLUS and GND are externally driven) ---
    pf_pins = libs["power:PWR_FLAG"][1]
    for i, net in enumerate(["BAT_PLUS", "GND"]):
        fpos = (63.5 + i * 25.4, 251.46)
        place("power:PWR_FLAG", fpos, 0, f"#FLG{i+1:02d}", "PWR_FLAG", pf_pins)
        fp = pin_abs(fpos, 0, pf_pins["1"])
        glabel(net, (fp[0], fp[1] + 2.54), 270)
        wire(fp, (fp[0], fp[1] + 2.54))

    # --- title-block-ish notes ---
    text_note("mokumoku-keeb LEFT half - Rev.A draft. GENERATED by scripts/generate_left_schematic.py - do not hand-edit wiring.", (40.64, 26.0), 2.0)
    text_note("Matrix: 5 rows x 7 cols, col2row (diode cathode -> ROW). 28 keys. ADR-0002.", (40.64, 30.5))

    lib_blob = "\n".join(
        "    " + raw.replace("\n", "\n    ") for raw, _ in libs.values()
    )
    sch = f'''(kicad_sch (version 20250114) (generator "generate_left_schematic") (generator_version "9.0")
  (uuid "{ROOT_UUID}")
  (paper "A2")
  (title_block
    (title "mokumoku-keeb left half")
    (rev "A-draft")
    (comment 1 "Generated - see scripts/generate_left_schematic.py")
  )
  (lib_symbols
{lib_blob}
  )
{chr(10).join(body)}
  (sheet_instances (path "/" (page "1")))
)
'''
    OUT_DIR.mkdir(parents=True, exist_ok=True)
    (OUT_DIR / f"{PROJECT}.kicad_sch").write_text(sch)
    pro = '{\n  "meta": { "filename": "%s.kicad_pro", "version": 3 },\n  "schematic": { "legacy_lib_list": [] }\n}\n' % PROJECT
    pro_path = OUT_DIR / f"{PROJECT}.kicad_pro"
    if not pro_path.exists():
        pro_path.write_text(pro)
    (OUT_DIR / "fp-lib-table").write_text(
        '(fp_lib_table (version 7)\n'
        '  (lib (name "mokumoku_keeb")(type "KiCad")'
        '(uri "${KIPRJMOD}/../footprints/mokumoku_keeb.pretty")(options "")(descr "project footprints"))\n)\n'
    )
    (OUT_DIR / "sym-lib-table").write_text(
        '(sym_lib_table (version 7)\n'
        '  (lib (name "mokumoku_keeb")(type "KiCad")'
        '(uri "${KIPRJMOD}/../symbols/mokumoku_keeb.kicad_sym")(options "")(descr "project symbols"))\n)\n'
    )
    print(f"wrote {OUT_DIR / (PROJECT + '.kicad_sch')}")
    print(f"symbols: {len(ref_counters)} kinds, refs: {ref_counters}")


if __name__ == "__main__":
    main()

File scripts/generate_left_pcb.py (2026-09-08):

#!/usr/bin/env python3
"""Generate the left-half PCB (placement + outline + antenna keep-out).

Run with KiCad's bundled Python (needs pcbnew):
  ~/Applications/KiCad/KiCad.app/Contents/Frameworks/Python.framework/Versions/*/bin/python3 \
      scripts/generate_left_pcb.py

Reads the netlist exported from the generated schematic, then builds
hardware/kicad/left/mokumoku_keeb_left.kicad_pcb:
  - 28 hotswap switches on a 19.05mm grid (key R0C0 center at (50, 50))
  - diodes on the back side between rows
  - nice!nano (antenna toward the top board edge, ADR-0007), nice!view header
  - JST PH on the back in the battery zone
  - cutout board outline per docs/key-layout.md
  - antenna keep-out rule area (all copper layers)
SW29 (slide switch) and SW30 (reset) have no verified footprint yet and are
NOT placed (Alps drawing / part selection pending).
Routing is a later phase - DRC "unconnected items" are expected.
"""

import re
import subprocess
import sys
import tempfile
from pathlib import Path

REPO = Path(__file__).resolve().parent.parent
LEFT = REPO / "hardware" / "kicad" / "left"
SCH = LEFT / "mokumoku_keeb_left.kicad_sch"
PCB = LEFT / "mokumoku_keeb_left.kicad_pcb"
KICAD_CLI = str(Path.home() / "Applications/KiCad/KiCad.app/Contents/MacOS/kicad-cli")
STD_FP = Path.home() / "Applications/KiCad/KiCad.app/Contents/SharedSupport/footprints"
PRJ_FP = REPO / "hardware" / "kicad" / "footprints"

import pcbnew  # noqa: E402
from pcbnew import VECTOR2I_MM  # noqa: E402

P = 19.05
X0, Y0 = 50.0, 50.0
KEYS = [(r, c) for r in range(4) for c in range(6)] + [(4, c) for c in range(3)] + [(3, 6)]

# board outline (same shape as concept mock; margin 1.5mm past keycap edge)
M = 9.525 + 1.5
TOP, LFT = Y0 - M, X0 - M
RGT = X0 + 6 * P + M
MAIN_BOT = Y0 + 3 * P + M
FOOT_R = X0 + 2 * P + M
FOOT_BOT = Y0 + 4 * P + M
OUTLINE = [(LFT, TOP), (RGT, TOP), (RGT, MAIN_BOT), (FOOT_R, MAIN_BOT),
           (FOOT_R, FOOT_BOT), (LFT, FOOT_BOT)]

NANO = (X0 + 6 * P, 57.0, 180)      # antenna end at top edge (ADR-0007)
NVIEW = (X0 + 6 * P - 5.08, 76.0, 90)  # 5-pin header centered on tab, below nano courtyard
JST = (162.0, 88.0, 0)              # back side, C6 tab free area (battery leads reach)

# antenna keep-out: nano top portion + 5mm margin, open to the top edge
KEEPOUT = [(NANO[0] - 8.89 - 5, TOP), (RGT, TOP),
           (RGT, 52.0), (NANO[0] - 8.89 - 5, 52.0)]


def tokenize(text):
    return re.findall(r'"(?:[^"\\]|\\.)*"|[()]|[^\s()"]+', text)


def parse(tokens, i=0):
    assert tokens[i] == "("
    i += 1
    out = []
    while tokens[i] != ")":
        if tokens[i] == "(":
            node, i = parse(tokens, i)
            out.append(node)
        else:
            out.append(tokens[i])
            i += 1
    return out, i + 1


def unq(s):
    return s[1:-1] if isinstance(s, str) and s.startswith('"') else s


def read_netlist():
    with tempfile.TemporaryDirectory() as td:
        np = Path(td) / "l.net"
        res = subprocess.run([KICAD_CLI, "sch", "export", "netlist", "--format",
                              "kicadsexpr", "-o", str(np), str(SCH)],
                             capture_output=True, text=True)
        if res.returncode != 0:
            sys.exit(res.stderr)
        node, _ = parse(tokenize(np.read_text()))
    comps, nets = {}, {}
    for sec in node:
        if isinstance(sec, list) and sec and sec[0] == "components":
            for c in sec[1:]:
                ref = unq([x[1] for x in c if isinstance(x, list) and x[0] == "ref"][0])
                fps = [x[1] for x in c if isinstance(x, list) and x[0] == "footprint"]
                comps[ref] = unq(fps[0]) if fps else ""
        if isinstance(sec, list) and sec and sec[0] == "nets":
            for n in sec[1:]:
                name = unq([x[1] for x in n if isinstance(x, list) and x[0] == "name"][0])
                for nd in n:
                    if isinstance(nd, list) and nd[0] == "node":
                        ref = unq([x[1] for x in nd if isinstance(x, list) and x[0] == "ref"][0])
                        pin = unq([x[1] for x in nd if isinstance(x, list) and x[0] == "pin"][0])
                        nets.setdefault(name, []).append((ref, pin))
    return comps, nets


def lib_dir(fpid):
    lib, _ = fpid.split(":")
    if lib == "mokumoku_keeb":
        return str(PRJ_FP / "mokumoku_keeb.pretty")
    return str(STD_FP / f"{lib}.pretty")


def main():
    comps, nets = read_netlist()
    board = pcbnew.NewBoard(str(PCB))

    netinfo = {}
    for name in nets:
        ni = pcbnew.NETINFO_ITEM(board, name)
        board.Add(ni)
        netinfo[name] = ni
    pad_net = {}
    for name, nodes in nets.items():
        for ref, pin in nodes:
            pad_net[(ref, pin)] = name

    placements = {}
    for i, (r, c) in enumerate(KEYS):
        x, y = X0 + c * P, Y0 + r * P
        placements[f"SW{i+1}"] = (x, y, 0, False)
        placements[f"D{i+1}"] = (x, y + 9.5, 0, True)
    placements["U1"] = (NANO[0], NANO[1], NANO[2], False)
    placements["J2"] = (NVIEW[0], NVIEW[1], NVIEW[2], False)
    placements["J1"] = (JST[0], JST[1], JST[2], True)

    skipped = []
    for ref, fpid in sorted(comps.items()):
        if ref.startswith("#"):
            continue
        if not fpid or ref not in placements:
            skipped.append(ref)
            continue
        name = fpid.split(":")[1]
        fp = pcbnew.FootprintLoad(lib_dir(fpid), name)
        assert fp, fpid
        fp.SetReference(ref)
        board.Add(fp)
        x, y, rot, flip = placements[ref]
        if flip:
            fp.Flip(fp.GetPosition(), False)
        fp.SetPosition(VECTOR2I_MM(x, y))
        fp.SetOrientationDegrees(rot)
        for pad in fp.Pads():
            key = (ref, pad.GetNumber())
            if key in pad_net:
                pad.SetNet(netinfo[pad_net[key]])
        if ref.startswith("D"):
            # keep the silk ref beside the diode (bottom rows would clip the edge)
            fp.Reference().SetPosition(VECTOR2I_MM(x - 6.4, y))
            fp.Reference().SetTextAngleDegrees(0)

    # board outline
    pts = OUTLINE + [OUTLINE[0]]
    for a, b in zip(pts, pts[1:]):
        sh = pcbnew.PCB_SHAPE(board)
        sh.SetShape(pcbnew.SHAPE_T_SEGMENT)
        sh.SetStart(VECTOR2I_MM(*a))
        sh.SetEnd(VECTOR2I_MM(*b))
        sh.SetLayer(pcbnew.Edge_Cuts)
        sh.SetWidth(int(0.1 * 1e6))
        board.Add(sh)
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

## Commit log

2026-09-08 Initial project scaffolding: docs, structure, and development rules
    - Add product requirements, key layout, architecture, electrical,
    mechanical, firmware, manufacturing, bring-up, verification docs
    - Add AGENTS.md with editing rules and ADR template
    - Add directory structure for KiCad, mechanical, ZMK, production
    - Add .gitignore for KiCad/CAD/build artifacts
2026-09-08 Phase 1: verify official specs, finalize matrix/GPIO plan and PCB scheme
    - Record verified nice!nano v2 pinout, charging specs, VDDH battery
    sensing, and nice!view dimensions/pinout in references.md
    - Finalize 5x7 physical-matching matrix and GPIO assignment (ADR-0002)
    - Adopt separate left/right PCBs for Rev.A (ADR-0001)
    - Fix board outline policy: cut out keyless regions, no bounding rectangle
2026-09-08 Phase 2: component selection (ADR-0003..0007)
    - Battery connector: JST PH 2.0mm S2B-PH-SM4-TB, polarity TBD
    - Power switch: Alps SSSS811101; no charge boost, battery <=500mAh
    - Matrix diode: 1N4148W SOD-123
    - Sockets: Kailh spring-pin (consule) primary for nice!nano
    - Antenna keep-out policy: edge-facing, +5mm all-layer keep-out
    - Record verified datasheets (Kailh PG151101S11, Alps, JST, 1N4148W)
2026-09-08 Phase 3: generated left-half schematic, ERC clean, netlist verified
    - Add nice_nano_v2 project symbol (verified against official pinout)
    - Add generate_left_schematic.py: emits left schematic from ADR-0002 data
    - Add verify_left_netlist.py: netlist cross-check against expected nets
    - Left schematic: 28 keys + diodes, JST/slide switch/reset/nice!view,
    polarity and BOOST warnings as schematic notes; ERC 0 violations
    [mokumoku_keeb_left.kicad_sch]
2026-09-08 Phase 4: footprints + concept mockups + case/power-switch decisions
    - Custom footprints (generated, datasheet-derived): Kailh MX hotswap,
    nice_nano_v2; standard-lib picks cross-checked (JST PH, SOD-123)
    - Verify Cherry MX official datasheet: plate 14.0mm cutout / 1.5mm
    thickness official, PCB ~1.5mm expectation (1.2mm caution)
    - Footprint verification status table in footprints/README.md
    - Concept mockups: top layout + side cross-section (assets/renders/)
    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
2026-09-08 Phase 5: left PCB placement, outline and antenna keep-out
    - generate_left_pcb.py: netlist-driven board generation; 28 keys on
    19.05mm grid, diodes on back, nano antenna-up per ADR-0007, JST on
    C6 tab, cutout Edge.Cuts outline, all-layer antenna keep-out zone
    - Assign footprints in schematic generator + project fp-lib-table
    - Fix footprint silk/back-text issues found by DRC
    - DRC: 0 violations besides expected unrouted items (routing pending)
    - SW29/SW30 intentionally unplaced (no verified footprints yet)
    - Add 3D renders (assets/renders/pcb-left-*.png)
    [mokumoku_keeb_left.kicad_pcb, mokumoku_keeb_left.kicad_sch]
